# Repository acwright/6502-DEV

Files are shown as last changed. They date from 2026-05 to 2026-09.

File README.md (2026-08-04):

6502-DEV
========

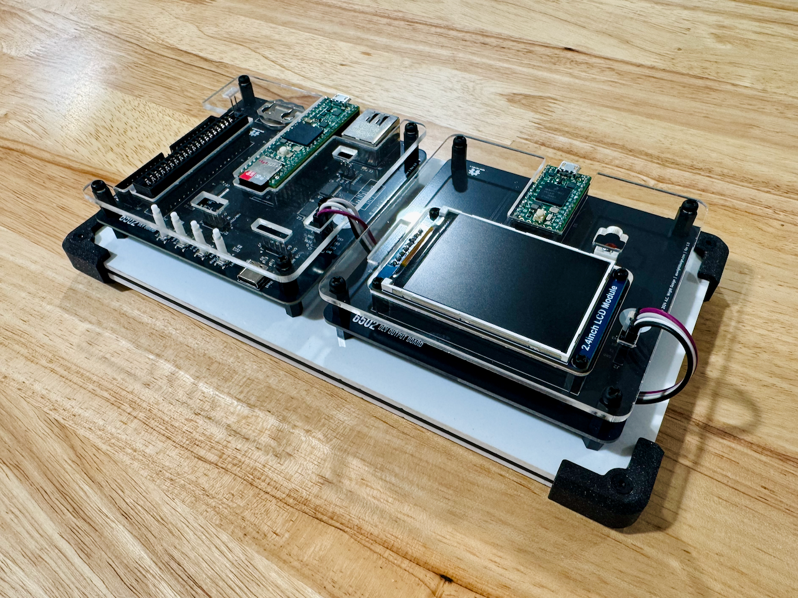
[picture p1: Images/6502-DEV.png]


An **AC6502** retro-style 8-bit computer based on the **65C02** microprocessor.

> 📖 **Guide:** [AC6502 Documentation](https://acwright.github.io/6502-DOCS/) — the user's and programmer's guide for the whole family.
> See [DEV's page in the family appendix](https://acwright.github.io/6502-DOCS/family/dev).

---

## Table of Contents

- [Overview](#overview)
- [Architecture](#architecture)
- [Systems](#systems)
- [Software](#software)
- [Hardware](#hardware)
  - [DEV Board](#dev-board)
  - [DEV Output Board](#dev-output-board)
- [Firmware](#firmware)
  - [DB Emulator](#db-emulator)
  - [DOB Display](#dob-display)
- [CAD](#cad)
- [Production](#production)
- [Schematics](#schematics)
- [Libraries](#libraries)
- [Bill of Materials](#bill-of-materials)
  - [DEV Board](#dev-board-1)
  - [DEV Output Board](#dev-output-board-1)
- [License](#license)

---

## Overview

The AC6502 ecosystem is a family of open-source, 65C02-based computers sharing a common architecture, memory map, and [BIOS](https://github.com/acwright/6502-BIOS). Each computer in the family is purpose-built for a different use case but runs the same software and firmware.

The **DEV** is an emulation-based development system. It replaces the physical 65C02 CPU with a [Teensy 4.1](https://www.pjrc.com/store/teensy41.html) running cycle-accurate 65C02 emulation via [vrEmu6502](https://github.com/visrealm/vrEmu6502).
## Architecture

All AC6502 computers share:

- **CPU**: 65C02 (or accurate emulation)
- **Memory**: 32KB RAM + 32KB ROM, with optional banked RAM expansion
- **Memory Map**: Standardized across the ecosystem — zero page, stack, I/O space ($8000–$9FFF), system ROM, and interrupt vectors at $FFFA–$FFFF
- **Bus**: 16-bit address bus, 8-bit bidirectional data bus, standard 65C02 control signals (RW, PHI2, RESET, IRQ, NMI, RDY, SYNC)
- **BIOS**: A common [BIOS](https://github.com/acwright/6502-BIOS) provides the kernel, monitor, and BASIC interpreter across all systems

## Systems

| Project | Description |
|---|---|
| [6502-ACE](https://github.com/acwright/6502-ACE) | All-in-one Computer Experience — A single board computer |
| [6502-COB](https://github.com/acwright/6502-COB) | Computer On a Backplane — Modular desktop computer with expandable card slots |
| [6502-DEV](https://github.com/acwright/6502-DEV) | Development Environment Vehicle — Emulation-based dev system (YOU ARE HERE) |
| [6502-KIM](https://github.com/acwright/6502-KIM) | Keypad Input Monitor - KIM-1 inspired minimal computer |
| [6502-VCS](https://github.com/acwright/6502-VCS) | Video Computer System — Cartridge-based retro gaming console |

## Software

| Project | Description |
|---|---|
| [6502-BIOS](https://github.com/acwright/6502-BIOS) | The shared BIOS (kernel, monitor, BASIC) for all AC6502 computers |
| [6502-EMULATOR](https://github.com/acwright/6502-EMULATOR) | Emulator for the whole family — desktop app, browser build, and a command line for scripted runs |
| [6502-PRG](https://github.com/acwright/6502-PRG) | Template project for writing assembly language programs |
| [6502-CRT](https://github.com/acwright/6502-CRT) | Template project for writing assembly language cartridges |
| [6502-ASM](https://github.com/acwright/6502-ASM) | Assembly language example programs and demos |
| [6502-BAS](https://github.com/acwright/6502-BAS) | BASIC program listings |
| [6502-WOZMON](https://github.com/acwright/6502-WOZMON) | Wozmon as a standalone ROM |
| [6502-NOP](https://github.com/acwright/6502-NOP) | An all-NOP ROM, for probing a board during bring-up |
| [6502-DOCS](https://github.com/acwright/6502-DOCS) | The documentation site — the guide, the printable reference cards, branding and label artwork |
| [cffs](https://github.com/acwright/cffs) | Builds CompactFlash disk images for the BIOS filesystem |
| [bastok](https://github.com/acwright/bastok) | Tokenizes BASIC listings into `.prg` images, and back |
| [bin2woz](https://github.com/acwright/bin2woz) | Converts a binary into a Wozmon serial upload |

## Hardware

This repository contains KiCad 7.0+ PCB designs for the two boards that make up the DEV system.

### DEV Board
`Hardware/DEV Board/`

The main board hosting the Teensy 4.1. Provides 65C02 bus emulation, SD card storage, Ethernet, USB keyboard/joystick input, and hardware control buttons (Run/Stop, Step, Reset, Frequency). Includes a bus connector and card slot with level shifters for optional real hardware expansion.

### DEV Output Board
`Hardware/DEV Output Board/`

The AV output board hosting a Teensy 4.0 and a 2.4" ILI9341 TFT LCD. Emulates a TMS9918A Video Display Processor and a MOS 6581 SID audio synthesizer, driven in real time via high-speed serial from the DEV Board. The DEV Board sends the same AV packets over USB at the same time, so a browser can render the output in parallel with this board — the two paths are simultaneous, not alternatives.

## Firmware

This repository contains [PlatformIO](https://platformio.org/)-based firmware for both boards.

### DB Emulator
`Firmware/DB Emulator/`

Firmware for the Teensy 4.1 on the DEV Board. Provides:

- Cycle-accurate 65C02 emulation
- SD card ROM/cartridge/program loading and memory snapshots
- Ethernet with mDNS (`6502.local`) and an embedded web control interface
- USB keyboard and joystick support (Xbox 360/One)
- AV packet output to both destinations at once — over USB to the browser (Web Serial API) and over hardware UART at 6 Mbps to the DOB Display
- Serial terminal interface (115200 baud)
- Hardware button control (Run/Stop, Step, Reset, Frequency)
- Variable CPU clock speed

See [Firmware/DB Emulator/README.md](./Firmware/DB%20Emulator/README.md) for setup and usage instructions.

### DOB Display
`Firmware/DOB Display/`

Firmware for the Teensy 4.0 on the DEV Output Board. Provides:

- TMS9918A VDP emulation (all four display modes, 256×192 active area)
- MOS 6581 SID audio emulation (3 voices, ADSR envelopes, PWM audio output)
- AV packet stream input at 6 Mbps over hardware UART from the DB Emulator (which also streams the same packets over USB to the browser)

See [Firmware/DOB Display/README.md](./Firmware/DOB%20Display/README.md) for setup and usage instructions.

## CAD
`CAD/`

3D-printable enclosure parts and laser-cut top panels for the DEV system.

## Production
`Production/`

JLCPCB-ready Gerber files and BOM/CPL for PCB fabrication and assembly.

## Schematics
`Schematics/`

PDF schematics for each board.

## Libraries
`Libraries/`

Shared KiCad symbol and footprint libraries used across all AC6502 hardware projects.

## Bill of Materials

### DEV Board

| Reference | Qty | Value | Description | LCSC | DigiKey | Mouser | Other |
|---|-----|---|---|---|---|---|---|
| BT1 | 1 | CR2032 | Battery Holder | | [BAT-HLD-001-THM-ND](https://www.digikey.com/en/products/filter?keywords=BAT-HLD-001-THM-ND) | [712-BAT-HLD-001-THM](https://www.mouser.com/ProductDetail/712-BAT-HLD-001-THM) | |
| C1–C8 | 8 | 100nF | SMD Capacitor | [C49678](https://www.lcsc.com/search?q=C49678) | | | |
| J1 | 1 | VBAT | Pin Header 1×2 2.54mm | | | | [AMAZON](https://www.amazon.com/Straight-Breakaway-Connector-Breadboard-Electronic/dp/B0FRZW75VS) |
| J2 | 1 | SPI | Pin Header 2×4 2.54mm | | | | [AMAZON](https://www.amazon.com/Uxcell-Double-Straight-Header-Strip/dp/B00X77A472) |
| J3 | 1 | PANEL | Pin Header 2×4 2.54mm | | | | [AMAZON](https://www.amazon.com/Uxcell-Double-Straight-Header-Strip/dp/B00X77A472) |
| J4 | 1 | 6502 Card Connector | Card Edge 2×20 2.54mm | | [A31723-ND](https://www.digikey.com/en/products/filter?keywords=A31723-ND) | [571-5-5530843-4](https://www.mouser.com/ProductDetail/571-5-5530843-4) | |
| J5 | 1 | 6502 Bus | Pin Socket 2×20 2.54mm | | | | [AMAZON](https://www.amazon.com/Female-Headers-Connector-Header-Raspberry/dp/B07DNHS2SJ) |
| J6 | 1 | USB Host | USB Type-C Receptacle | [C2988369](https://www.lcsc.com/search?q=C2988369) | | | |
| J7 | 1 | USB HOST | Pin Header 1×5 2.54mm | | | | [AMAZON](https://www.amazon.com/Straight-Breakaway-Connector-Breadboard-Electronic/dp/B0FRZW75VS) |
| J8 | 1 | RJ45 w/ LEDs | RJ45 8P8C Shielded | | [1278-1052-ND](https://www.digikey.com/en/products/filter?keywords=1278-1052-ND) | | |
| J9 | 1 | ETHERNET | Pin Header 2×3 2.00mm | | | | [AMAZON](https://www.amazon.com/uxcell-2-0mm-Pitch-Double-Headers/dp/B00899WM00) |
| R1–R8 | 8 | 1kΩ | SMD Resistor | [C17513](https://www.lcsc.com/search?q=C17513) | | | |
| R9, R10 | 2 | 56kΩ | SMD Resistor | [C169923](https://www.lcsc.com/search?q=C169923) | | | |
| R11 | 1 | 150Ω | SMD Resistor | [C17471](https://www.lcsc.com/search?q=C17471) | | | |
| SW1 | 1 | Run/Stop | Tact Push Button | [C318884](https://www.lcsc.com/search?q=C318884) | | | |
| SW2 | 1 | Step | Tact Push Button | [C318884](https://www.lcsc.com/search?q=C318884) | | | |
| SW3 | 1 | Clock | Tact Push Button | [C318884](https://www.lcsc.com/search?q=C318884) | | | |
| SW4 | 1 | Reset | Tact Push Button | [C318884](https://www.lcsc.com/search?q=C318884) | | | |
| U1–U3, U5, U6 | 5 | SN74LVC4245APWR | Octal Bus Transceiver | [C7859](https://www.lcsc.com/search?q=C7859) | | | |
| U4 | 1 | Teensy 4.1 | Microcontroller | | | | [PJRC](https://www.pjrc.com/store/teensy41.html) |

### DEV Output Board

| Reference | Qty | Value | Description | DigiKey | Mouser | Other |
|---|-----|---|---|---|---|---|
| C1 | 1 | 3.3nF | Disc Capacitor | | | [AMAZON](https://www.amazon.com/PANMILED-Multilayer-Monolithic-Capacitors-Assortment/dp/B0CYQ1Z4G5) |
| J1 | 1 | AUDIO | JST XH 1×2 2.50mm | [455-2247-ND](https://www.digikey.com/en/products/filter?keywords=455-2247-ND) | | |
| J2 | 1 | SERIAL | Pin Header 1×4 2.54mm | | | [AMAZON](https://www.amazon.com/Straight-Breakaway-Connector-Breadboard-Electronic/dp/B0FRZW75VS) |
| R6 | 1 | 1kΩ | Axial Resistor | [RNF18FTD1K00CT-ND](https://www.digikey.com/en/products/filter?keywords=RNF18FTD1K00CT-ND) | | [AMAZON](https://www.amazon.com/ALLECIN-8W-Metal-Film-Resistor/dp/B0C77TM3NR) |
| U1 | 1 | Waveshare LCD Header | Pin Header 1×8 2.54mm | | | [AMAZON](https://www.amazon.com/Straight-Breakaway-Connector-Breadboard-Electronic/dp/B0FRZW75VS) |
| U2 | 1 | Teensy 4.0 | Microcontroller | | | [PJRC](https://www.pjrc.com/store/teensy40.html) |
| U3 | 1 | Waveshare 2.4in LCD | 2.4" ILI9341 TFT LCD | | | [AMAZON](https://www.amazon.com/dp/B08H24H7KX) |

## License

Hardware designs are released under the [CERN Open Hardware Licence Version 2 – Permissive](https://ohwr.org/cern_ohl_p_v2.txt).  
Firmware is released under the MIT License — [DB Emulator](./Firmware/DB%20Emulator/LICENSE), [DOB Display](./Firmware/DOB%20Display/LICENSE).

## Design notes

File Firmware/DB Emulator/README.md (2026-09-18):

# DB Emulator

A 65C02 CPU emulator firmware for the Teensy 4.1 microcontroller. This project provides a complete hardware-accelerated 65C02 emulation platform with support for RAM, ROM, cartridge loading, I/O devices, and network control.

## Overview

DB Emulator transforms a Teensy 4.1 into a powerful 65C02 computer system emulator. It emulates the complete 65C02 CPU instruction set, memory management, and provides hardware interfaces for keyboards, joysticks, and network connectivity. The emulator can be controlled via serial terminal or through the embedded [web interface](html/README.md). Audio (SID) and video (TMS9918A) register writes are streamed simultaneously to two destinations: over USB (`SerialUSB2`) to the browser, and over the hardware UART (`Serial7` at 6 Mbps) to the DOB Display board for rendering on the ILI9341 TFT and PWM audio output.

### Features

- **Complete 65C02 CPU Emulation**: Accurate cycle-by-cycle emulation using [vrEmu6502](https://github.com/visrealm/vrEmu6502)
- **Memory Management**: 
  - Base RAM: up to 32KB (configurable)
  - Banked RAM: 32KB (default), up to 512KB with PSRAM installed
  - ROM support (full 32KB `BIOS.bin` image; 24KB visible at `$A000-$FFFF` once I/O overlays `$8000-$9FFF`)
  - Cartridge loading (16KB)
- **I/O Support**:
  - USB Keyboard input
  - USB Joystick support (Xbox 360/One controllers)
  - RAM Card (I/O 1 and I/O 2, banked RAM)
  - RTC Card (I/O 3, DS1511Y real-time clock)
  - Storage Card (I/O 4, emulated 256MB CompactFlash backed by `Storage.bin` on SD)
  - Serial Card (I/O 5, Rockwell R6551 ACIA, bound to `SerialUSB1` — the BIOS serial console). It models the standard Serial Card with its `CTS EN` jumper at ground, as every board is built: CTS, DCD and DSR are all tied low, so CTS never stops the transmitter, DCD never stops the receiver, and DSR and DCD both read 0 (active low). There is no card picker and no jumper setting, and none of the Serial Card Pro's lines. Clearing DTR (command bit 0) still turns the receiver, the transmitter and the interrupts off, as it does inside the real chip even though the card leaves the DTR pin unconnected. One thing the real chip does is deliberately left out: a TIC of `00` (command bits 3-2) raises RTS here but does not also stop the transmitter, because this firmware embeds no ROM and cannot check that the image on the SD card is one that survives it — see the comment on `SerialCard::transmitterEnabled`
  - GPIO Card (I/O 6, 65C22 VIA with keyboard/joystick attachments)
  - Sound Card (I/O 7, SID — MOS 6581 emulation, streamed to web interface and DOB Display)
  - Video Card (I/O 8, TMS9918A emulation, streamed to web interface and DOB Display)
- **Storage**:
  - SD card support for loading ROMs, cartridges, and programs
  - Memory snapshot functionality
- **Network Features**:
  - Ethernet connectivity via [QNEthernet](https://github.com/ssilverman/QNEthernet)
  - mDNS discovery (hostname: `6502.local`)
  - Embedded web server with REST API
  - Embedded web control interface (served from SD card)
- **Audio/Video Streaming**: every AV packet is sent to both destinations at once
  - Over USB (`SerialUSB2`) to the browser — SID register writes for Web Audio API synthesis, TMS9918A register writes for canvas rendering, via the Web Serial API (Chrome or Edge required)
  - Over the hardware UART (`Serial7` at 6 Mbps) to the DOB Display board, which renders the same register writes on an ILI9341 TFT with PWM audio output
- **Browser Keyboard Input**: Forwards keyboard events from the web interface to the emulator via REST API
- **Control Options**:
  - Serial terminal interface (115200 baud)
  - Physical buttons (Run/Stop, Step, Reset, Frequency)
  - Web API control
- **Variable Clock Speed**: Adjustable CPU frequency from very slow to maximum speed
- **Real-Time Clock**: TimeLib integration for timestamped operations

## Prerequisites

### Hardware Requirements

- **Teensy 4.1** microcontroller
- **Ethernet module** (built-in on Teensy 4.1)
- **MicroSD card** (optional, for loading ROMs/programs)
- **Development board** compatible with one of the supported configurations
- **USB cable** for programming and serial communication
- **Optional**:
  - USB keyboard
  - USB joystick (Xbox 360/One)
  - PSRAM chip (for extended memory support)

### Software Requirements

- **PlatformIO Core** or **PlatformIO IDE** (VS Code extension)
- **Python 3.x** (usually installed with PlatformIO)
- **Git** (for cloning dependencies)
- **Chromium-based browser** (Chrome or Edge) required for audio/video streaming via Web Serial API
- **Serial terminal software** (optional):
  - CoolTerm (recommended)
  - Arduino Serial Monitor
  - PlatformIO Serial Monitor
  - screen/minicom (Linux/macOS)

### Development Tools (Optional)

- **Visual Studio Code** with PlatformIO extension
- **Teensy Loader Application** (for manual flashing)

## Installation

### 1. Install PlatformIO

#### Option A: PlatformIO IDE (Recommended)

1. **Install Visual Studio Code** from [code.visualstudio.com](https://code.visualstudio.com/)

2. **Install PlatformIO IDE extension**:
   - Open VS Code
   - Go to Extensions (Ctrl+Shift+X / Cmd+Shift+X)
   - Search for "PlatformIO IDE"
   - Click Install

#### Option B: PlatformIO Core (Command Line)

```bash
# macOS/Linux
python3 -c "$(curl -fsSL https://raw.githubusercontent.com/platformio/platformio/master/scripts/get-platformio.py)"

# Or using pip
pip install -U platformio
```

### 2. Clone or Navigate to Project

```bash
cd /path/to/6502/Firmware/DB\ Emulator
```

### 3. Install Dependencies

PlatformIO will automatically install the required libraries on first build:

- **[QNEthernet](https://github.com/ssilverman/QNEthernet)** (v0.27.0+): Ethernet library for Teensy 4.1
- **[ArduinoJson](https://github.com/bblanchon/ArduinoJson)** (v7.0.4+): JSON parsing and generation
- **[AsyncWebServer_Teensy41](https://github.com/khoih-prog/AsyncWebServer_Teensy41)** (v1.7.0+): Asynchronous web server

Additional dependencies included in the project:
- **[vrEmu6502](https://github.com/visrealm/vrEmu6502)**: 6502 CPU emulator core (included in `lib/6502/vrEmu6502/`)
- **TimeLib**: Real-time clock support
- **Bounce2**: Button debouncing library
- **SD**: SD card file system
- **EEPROM**: Non-volatile storage
- **USBHost_t36**: USB host support for Teensy

## Configuration

### Build Flags

You can enable/disable features by uncommenting build flags in `platformio.ini`:

```ini
build_flags = 
    -D USB_TRIPLE_SERIAL    ; Enable triple serial ports (SerialUSB1 + SerialUSB2 for AV streaming)
    ; -D MOUSE_DEBUG        ; Enable mouse debugging output
    ; -D JOYSTICK_DEBUG     ; Enable joystick debugging output
    ; -D KEYBOARD_DEBUG     ; Enable keyboard debugging output
    -D MEM_EXTMEM           ; Use external PSRAM
```

### SD Card Setup (Optional)

1. **Format SD card** as FAT32
2. **Create directories** on the SD card:
   ```
   /ROMs/       - BIOS and operating system ROMs
   /Carts/      - Cartridge images
   /Programs/   - User programs
   /Snapshots/  - Memory snapshots
   /WWW/        - Embedded web application (See README in /html folder)
   ```
3. **Place ROM or PRG files** (.bin or .prg format) in appropriate directories

**Auto-boot Configuration**:
- Place `BIOS.bin` in the `ROMs` directory for automatic loading

## Building and Uploading

### Using PlatformIO IDE (VS Code)

1. **Open the project** in VS Code (File → Open Folder)

2. **Build the project**:
   - Click the ✓ (Build) button in the status bar
   - Or: Terminal → Run Build Task
   - Or: Press `Ctrl+Alt+B` / `Cmd+Alt+B`

3. **Upload to Teensy**:
   - Connect Teensy 4.1 via USB
   - Click the → (Upload) button in the status bar
   - Or: Use the upload task from the command palette
   - The Teensy will automatically enter bootloader mode

### Using PlatformIO Core (Command Line)

```bash
# Build for DevBoard 1 (Rev 1.0 and newer)
platformio run -e devboard_1

# Build for DevBoard 0 (Rev 0.0 legacy board)
platformio run -e devboard_0

# Upload to Teensy
platformio run -e devboard_1 --target upload

# Build and upload
platformio run -e devboard_1 -t upload

# Open serial monitor
platformio device monitor -b 115200

# Build, upload, and monitor
platformio run -e devboard_1 -t upload && platformio device monitor -b 115200
```

### Manual Upload with Teensy Loader

1. Build the firmware using PlatformIO
2. Locate the compiled `.hex` file in `.pio/build/devboard_X/firmware.hex`
3. Open Teensy Loader application
4. Load the `.hex` file
5. Press the button on the Teensy to enter bootloader mode
6. Click "Program" in Teensy Loader

## Usage

### Serial Terminal Control

Connect to the Teensy via serial terminal at **115200 baud**:

```bash
# Using PlatformIO
platformio device monitor -b 115200

# Using screen (macOS/Linux)
screen /dev/ttyACM0 115200

# Using CoolTerm
# Set port to Teensy, baud rate to 115200
```

### Serial Commands

Once connected, you'll see the emulator banner and status. Available commands:

#### Execution Control
- **`R`** - Run/Stop: Toggle emulator execution
- **`S`** - Step: Execute one CPU instruction (when stopped)
- **`K`** - Tick: Execute one clock cycle (when stopped)
- **`T`** - Reset: Hardware reset of the emulator

#### Memory Management
- **`A`** - Toggle RAM: Enable/disable RAM
- **`O`** - Toggle ROM: Enable/disable ROM
- **`L`** - Toggle Cart: Enable/disable cartridge

#### File Management
- **`M`** - List ROMs: Show available ROM files from SD card
- **`C`** - List Carts: Show available cartridge files
- **`U`** - List Programs: Show available user programs
- **`0-7`** - Load File: Load the selected file (after listing)
- **`[`** - Previous Page: Navigate file lists
- **`]`** - Next Page: Navigate file lists

#### Configuration
- **`+`** - Increase Frequency: Speed up CPU clock
- **`-`** - Decrease Frequency: Slow down CPU clock

#### Information & Debugging
- **`F`** - Info: Display system information and status
- **`G`** - Log: Show current CPU state
- **`P`** - Snapshot: Save current RAM state to SD card

### Web Control Interface

1. **Ensure Teensy is connected** to your network via Ethernet

2. **Note the IP address** from the serial output on boot

3. **Access via mDNS** (if supported):
   ```
   http://6502.local/
   ```

4. **Or access via direct IP**:
   ```
   http://192.168.1.XXX/
   ```

5. **Use the web interface** to control the emulator (see [Web Interface documentation](html/README.md))

#### Audio/Video Streaming

Every SID and TMS9918A register write is emitted as a 4-byte AV packet, and `avSend()` in `lib/6502/IO/AVStream.h` writes each packet to **both** outputs on every call. The two paths are simultaneous, not alternatives — neither has to be connected for the other to work.

**Browser rendering (USB, `SerialUSB2`)**

- The Teensy must be USB-connected to the same machine running the browser
- Click **Connect AV** in the VIDEO panel to open the USB serial link
- Requires **Chrome or Edge** (Web Serial API); requires HTTPS or localhost
- Audio and video are rendered entirely in the browser; the Teensy streams register writes only
- Click **Mute** to toggle audio output

**Hardware rendering (`HWSERIAL` / `Serial7` at 6 Mbps)**

The same packets go out the hardware UART to the DEV Output Board, whose [DOB Display](../DOB%20Display/README.md) firmware opens `Serial1` at the same 6000000 baud and parses the identical 4-byte format. It renders the TMS9918A output on the 2.4" ILI9341 TFT and the SID output as PWM audio. Any other device speaking the same protocol can be attached instead.

### Physical Controls

If your development board has physical buttons:

- **INT/CLK Button**: Change clock frequency
- **STEP Button**: Execute one instruction
- **RUN/STOP Button**: Toggle execution
- **RESET Button**: Hardware reset (DevBoard 1 only)

## API Endpoints

The embedded web server provides RESTful API endpoints:

### GET /info
Returns system information and CPU state in JSON format:
```json
{
  "address": 65535,
  "cartEnabled": true,
  "cartFile": "game.bin",
  "cpuAccumulator": 0,
  "cpuOpcodeCycle": 0,
  "cpuPC": 65520,
  "cpuStackPointer": 255,
  "cpuStatus": 32,
  "cpuX": 0,
  "cpuY": 0,
  "data": 234,
  "freqLabel": "1 MHz",
  "freqPeriod": 1,
  "ipAddress": "192.168.1.100",
  "isRunning": false,
  "lastSnapshot": 1234567890,
  "programFile": "",
  "romFile": "BIOS.bin",
  "rtc": 1737590400,
  "rw": 1,
  "soundEnabled": true,
  "version": "1.0",
  "videoEnabled": true,
  "avStreamConnected": false
}
```

### GET /memory?target={ram|rom}&page={n}
Returns a memory dump, one 256-byte page per request:
- `target`: `ram` or `rom` (required; returns 400 if missing or any other value)
- `page`: Page number, `0`-`127` for both targets (required; returns 400 if missing or out of range)
  - RAM page `n` covers `$0000 + (n * $100)`, so page 0 is `$0000` and page 127 is `$7F00`
  - ROM page `n` is an offset from `ROM_START`, covering `$8000 + (n * $100)` — the visible ROM window at `$A000` begins at page 32
- Optional: `formatted=true` returns `text/plain` as space-separated hex bytes; omitted, the response is raw `application/octet-stream`

### GET /storage?target={rom|cart|program}&page={n}
Lists files in storage:
- `target`: `rom`, `cart`, or `program`
- `page`: Page number for pagination
- Returns JSON array of filenames

### GET /load?target={rom|cart|program}&filename={name}
Loads a file from SD card:
- `target`: Memory region to load into
- `filename`: Name of file to load

### GET /control?command={cmd}
Executes control command:
- `command`: Single letter command (same as serial commands)
- Examples: `r` (run/stop), `s` (step), `t` (reset), `+` (inc freq)

### GET /keyboard?action={down|up}&keycode={XX}
Forwards browser keyboard events to the emulator:
- `action`: `down` or `up` (required; returns 400 if missing or invalid)
- `keycode`: 1–2 character hex string representing a USB HID keycode (e.g. `04` for 'a') (required; returns 400 if missing)
- Returns 200 on success

**Note:** Audio/video data does not flow over REST. It streams over USB (`SerialUSB2`, Web Serial API) and over the hardware UART (`Serial7`) to the DOB Display, simultaneously. See the Audio/Video Streaming section above.

## Troubleshooting

### Build Errors

**Problem**: Library dependencies not found

**Solutions**:
- Run `platformio lib install` to fetch dependencies
- Delete `.pio` folder and rebuild
- Check internet connection for library downloads

**Problem**: Compilation errors with PSRAM

**Solutions**:
- Ensure `MEM_EXTMEM` flag matches your hardware configuration
- Check PSRAM wiring and connections

### Upload Issues

**Problem**: Teensy not detected

**Solutions**:
- Install Teensy Udev rules (Linux) or drivers (Windows)
- Press the physical button on Teensy to enter bootloader mode
- Try a different USB cable or port
- Check `platformio device list` to see connected devices

**Problem**: Upload fails or times out

**Solutions**:
- Manually press Teensy button during upload
- Use Teensy Loader application instead
- Update Teensy udev rules/drivers

### Runtime Issues

**Problem**: Emulator doesn't start or crashes

**Solutions**:
- Check serial output for error messages
- Verify SD card is properly formatted (FAT32)
- Ensure ROM files are valid 65C02 binaries
- Reset via serial command `T` or power cycle

**Problem**: Network features not working

**Solutions**:
- Verify Ethernet cable is connected
- Check DHCP is available on your network
- Look for IP address in serial output
- Try accessing via direct IP instead of mDNS
- Ensure firewall allows port 80

**Problem**: USB devices not recognized

**Solutions**:
- Check device compatibility (Xbox controllers work best)
- Try different USB ports on the hub
- Verify USB host power supply is adequate
- Enable debug flags to see USB enumeration

**Problem**: SD card files not loading

**Solutions**:
- Verify SD card is formatted as FAT32
- Check file permissions and naming
- Ensure directories exist: `/ROMs/`, `/Carts/`, `/Programs/`
- Files should have `.bin` extension
- Try reinserting SD card

### AV Streaming Issues

**Problem**: Connect AV button not visible

**Solutions**:
- Must use Chrome or Edge (Web Serial API is not supported in Firefox or Safari)
- The Web Serial API requires a **secure context**. When accessing via `http://6502.local` (plain HTTP), Chrome hides the API even though your browser supports it. Choose one of the following workarounds:

  **Option 1 — Chrome flag (easiest, for local development)**
  1. In Chrome, navigate to `chrome://flags/#unsafely-treat-insecure-origin-as-secure`
  2. Add `http://6602.local` to the list and set it to **Enabled**
  3. Relaunch Chrome

  **Option 2 — Serve over HTTPS**
  Configure the Teensy's web server with a self-signed TLS certificate. The browser will show a certificate warning; accept it once and the API will become available.

  **Option 3 — Local proxy via localhost**
  Run a local reverse proxy (e.g. `nginx` or `caddy`) that forwards `http://localhost` to `http://6602.local`. Because `localhost` is always treated as a secure context, the Web Serial API will be available.

**Problem**: No video or audio after connecting

**Solutions**:
- Verify USB cable supports data (not charge-only)
- Check `SerialUSB2` is initialized (`USB_TRIPLE_SERIAL` build flag must be set)
- Try disconnecting and reconnecting

**Problem**: Audio glitches or dropouts

**Solutions**:
- Lower the CPU frequency
- Ensure the browser tab is not throttled or backgrounded
- Close other audio-intensive applications

## Development

### Project Structure

```
DB Emulator/
├── lib/
│   └── 6502/                 # Custom 6502 emulation library
│       ├── 6502.h            # Main library header
│       ├── constants.h       # System constants
│       ├── macros.h          # Utility macros
│       ├── pins.h            # Pin definitions
│       ├── CPU/              # CPU emulator wrapper
│       │   └── [vrEmu6502](https://github.com/visrealm/vrEmu6502)/        # Core 6502 emulator
│       ├── RAM/              # RAM emulation
│       ├── ROM/              # ROM emulation
│       ├── Cart/             # Cartridge support
│       └── IO/               # I/O device emulation
│           ├── AVStream.h    # AV streaming protocol (SerialUSB2 + HWSERIAL)
│           ├── SoundCard.*   # SID (MOS 6581) emulation
│           └── VideoCard.*   # TMS9918A emulation
├── src/
│   └── main.cpp              # Main firmware code
├── include/                  # Additional headers
├── test/                     # Unit tests
├── html/                     # Web interface source
└── platformio.ini            # PlatformIO configuration
```

### Adding Features

1. **New I/O Device**: Extend the `IO` class in `lib/6502/IO/`
2. **Memory Extensions**: Modify memory maps in `constants.h`
3. **New Commands**: Add cases to `onCommand()` in `main.cpp`
4. **Web API**: Add routes in `initServer()` function

### Memory Map

```
$0000 - $00FF : Zero Page
$0100 - $01FF : Stack
$0200 - $02FF : Input Buffer
$0300 - $03FF : Kernal Variables
$0400 - $07FF : User Variables
$0800 - $7FFF : Program RAM (30KB)
$8000 - $83FF : I/O Slot 1 (1KB) - RAM Card
$8400 - $87FF : I/O Slot 2 (1KB) - RAM Card
$8800 - $8BFF : I/O Slot 3 (1KB) - RTC Card
$8C00 - $8FFF : I/O Slot 4 (1KB) - Storage Card
$9000 - $93FF : I/O Slot 5 (1KB) - Serial Card
$9400 - $97FF : I/O Slot 6 (1KB) - GPIO Card
$9800 - $9BFF : I/O Slot 7 (1KB) - Sound Card (SID)
$9C00 - $9FFF : I/O Slot 8 (1KB) - Video Card (TMS9918A)
$A000 - $BFFF : ROM (8KB)
$C000 - $FFFF : ROM/Cartridge (16KB)
```

**Note**: The cartridge space ($C000-$FFFF) can be used for either ROM or cartridge data depending on configuration.

### Debug Output

Enable debug flags in `platformio.ini` for verbose logging:

```ini
-D KEYBOARD_DEBUG    ; Log all keyboard events
-D JOYSTICK_DEBUG    ; Log joystick button presses
```

## Performance

- **Maximum Emulation Speed**: 1 MHz (Teensy 4.1 @ 600 MHz)
- **Accurate Timing**: Down to microsecond precision
- **Memory**: 32KB base RAM + 32KB banked RAM (default), up to 544KB total with PSRAM (32KB base + 512KB banked)
- **Storage**: Limited only by SD card size

## Related Documentation

- [Web Interface (html/)](html/README.md)
- [PlatformIO Documentation](https://docs.platformio.org/)
- [Teensy 4.1 Documentation](https://www.pjrc.com/store/teensy41.html)
- [6502 CPU Reference](http://www.6502.org/)

## License

See LICENSE file in project root.

## Credits

- © 2024 A.C. Wright Design
- Based on [vrEmu6502](https://github.com/visrealm/vrEmu6502) by Troy Schrapel
- Uses [QNEthernet](https://github.com/ssilverman/QNEthernet) library by Shawn Silverman
- Uses [AsyncWebServer_Teensy41](https://github.com/khoih-prog/AsyncWebServer_Teensy41) library by Khoi Hoang
- Uses [ArduinoJson](https://github.com/bblanchon/ArduinoJson) library by Benoit Blanchon

## Version History

- **v1.0.0**: Initial release with full 65C02 emulation, network support, and web API

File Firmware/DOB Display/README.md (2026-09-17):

# DOB Display

DOB Display is the AV output firmware for the DOB (DEV Output Board). It emulates a TMS9918A Video Display Processor and a MOS 6581 SID audio synthesizer, driven in real time by AV packets from the DB Emulator over high-speed hardware serial.

## Features

- **TMS9918A VDP Emulator** - Full software emulation of all four TMS9918A display modes
- **320x240 Display with Borders** - 256×192 active area centered in a 320×240 canvas with TMS9918-style color borders
- **8-bit Indexed Framebuffer** - 76,800-byte indexed framebuffer with 16-entry RGB565 TMS9918A palette; half the RAM of a 16-bit framebuffer
- **SID Audio Emulator** - 3-voice MOS 6581 software synthesizer with triangle, sawtooth, pulse, and noise waveforms and full ADSR envelopes, output via 8-bit PWM at 44.1 kHz
- **AV Packet Protocol** - 4-byte AV packet stream received at 6 Mbps over hardware UART (Serial1) from the DB Emulator
- **Dual Serial Input** - USB Serial accepted as a fallback for testing without hardware
- **~60 FPS Rendering** - Full-frame re-render from VRAM state every ~17 ms

## Hardware

- **MCU**: Teensy 4.0 (600 MHz ARM Cortex-M7)
- **Display**: ILI9341 320×240 TFT LCD
- **Audio**: 8-bit PWM output (pin 14) into passive speaker via RC low-pass filter
- **Communication**: USB Serial + hardware UART Serial1 at 6 Mbps

### Audio Hardware Notes

The audio output on pin 14 is a PWM signal with a ~2.34 MHz carrier. To drive a small 8Ω speaker you need an RC low-pass filter between pin 14 and the speaker:

- **R**: 1 kΩ
- **C**: 3.3 nF to ground (f_c ≈ 48 kHz)

This removes the PWM carrier while passing the full audio band.

## AV Packet Format

All communication uses 4-byte packets: `{ 0xAA, type, a, b }`

| Type | Value | Description |
|---|---|---|
| `AV_TYPE_SOUND` | `0x01` | SID register write: `a` = register (0x00–0x1F), `b` = value |
| `AV_TYPE_VIDEO_DATA`  | `0x02` | VRAM data write at current address pointer (auto-increments) |
| `AV_TYPE_VIDEO_REG` | `0x03` | TMS9918A register write: `a` = register (0–7), `b` = value |
| `AV_TYPE_VIDEO_ADDR`  | `0x04` | Set VRAM address: `a` = high 6 bits, `b` = low 8 bits |
| `AV_TYPE_RESET` | `0xFE` | Reset all VRAM, TMS9918A registers, SID state, and address pointer |

## Display Modes

| M1 | M2 | M3 | Mode |
|----|----|----|---|
| 0  | 0  | 0  | Graphics I — 32×24 tiles, per-8-char color |
| 0  | 0  | 1  | Graphics II — 32×24 tiles, per-pixel color |
| 1  | 0  | 0  | Text — 40×24 tiles, 6px wide, R7 fg/bg |
| 0  | 1  | 0  | Multicolor — 64×48 fat pixels (4×4 each) |

Sprites are rendered in all modes except Text (up to 32 sprites, max 4 visible per scanline, 8×8 or 16×16, with optional magnification).

## Installation

### Prerequisites

- [PlatformIO](https://platformio.org/) - Cross-platform build system
- [Visual Studio Code](https://code.visualstudio.com/) (recommended) with PlatformIO extension
- Teensy 4.0 board
- ILI9341 compatible TFT display

### Hardware Setup

Connect the display and speaker to your Teensy 4.0 according to the pin definitions in `lib/DOBDisplay/pins.h`.

## Building and Uploading

### Using PlatformIO CLI

1. Clone the repository:
   ```bash
   git clone <repository-url>
   cd "DOB Display"
   ```

2. Build the project:
   ```bash
   pio run
   ```

3. Upload to Teensy 4.0:
   ```bash
   pio run --target upload
   ```

### Using VS Code

1. Open the project folder in VS Code
2. Click the PlatformIO icon in the sidebar
3. Under "Project Tasks" → "teensy" → "General":
   - Click "Build" to compile
   - Click "Upload" to flash the firmware

## Project Structure

```
DOB Display/
├── src/
│   └── main.cpp              # Main firmware — VDP emulator, SID engine, AV packet processing
├── lib/
│   └── DOBDisplay/
│       ├── constants.h       # AV protocol constants, display geometry, TMS9918A RGB565 palette
│       ├── pins.h            # Hardware pin assignments
│       └── DOBDisplay.h # Main library header
├── platformio.ini            # Build configuration
└── README.md
```

## License

See [LICENSE](LICENSE) for details.

## Author

© 2026 A.C. Wright Design

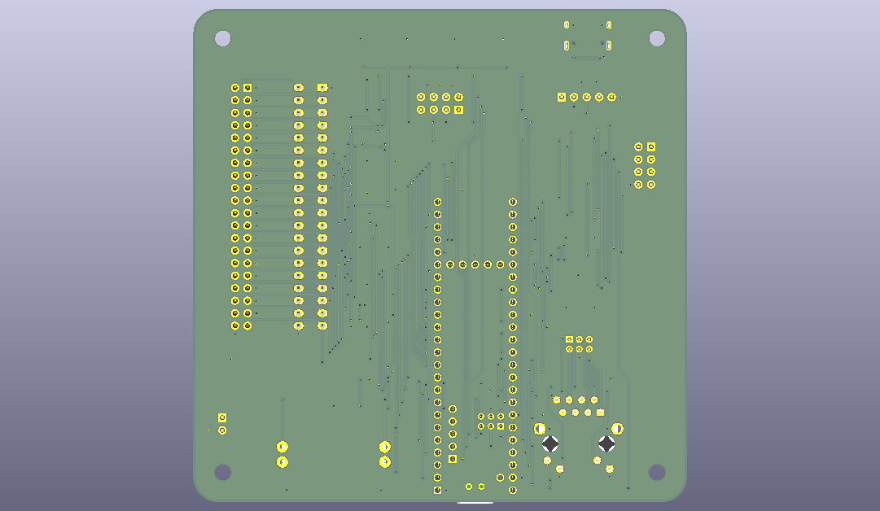
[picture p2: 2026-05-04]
CAD/Images/DEV Board/Rev 1.0/Back.png

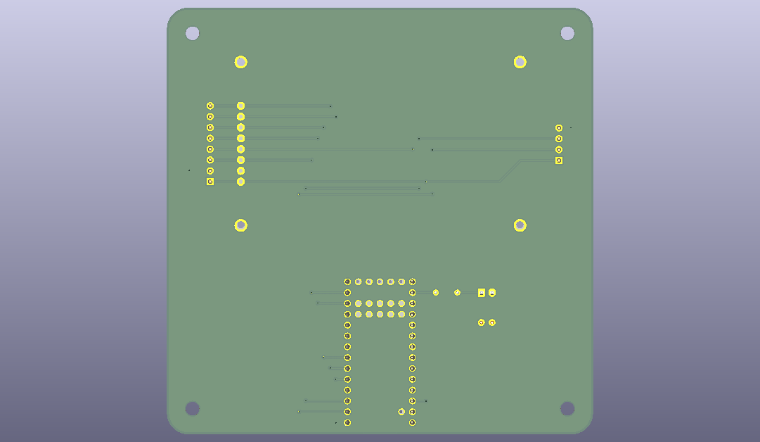
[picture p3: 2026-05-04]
CAD/Images/DEV Output Board/Rev 1.0/Back.png

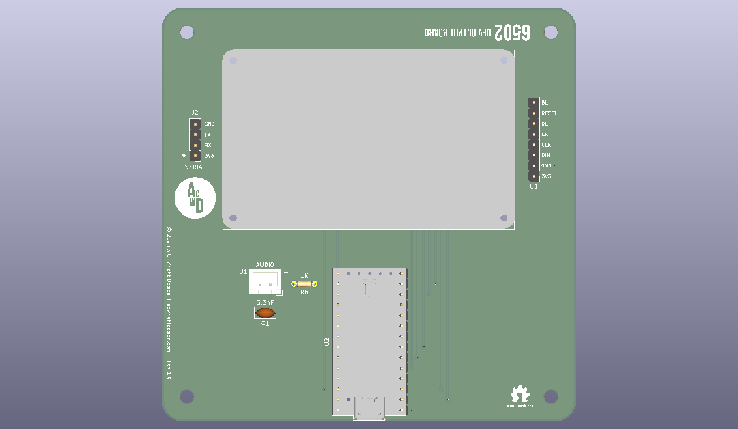
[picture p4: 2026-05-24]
CAD/Images/DEV Output Board/Rev 1.0/Front.png

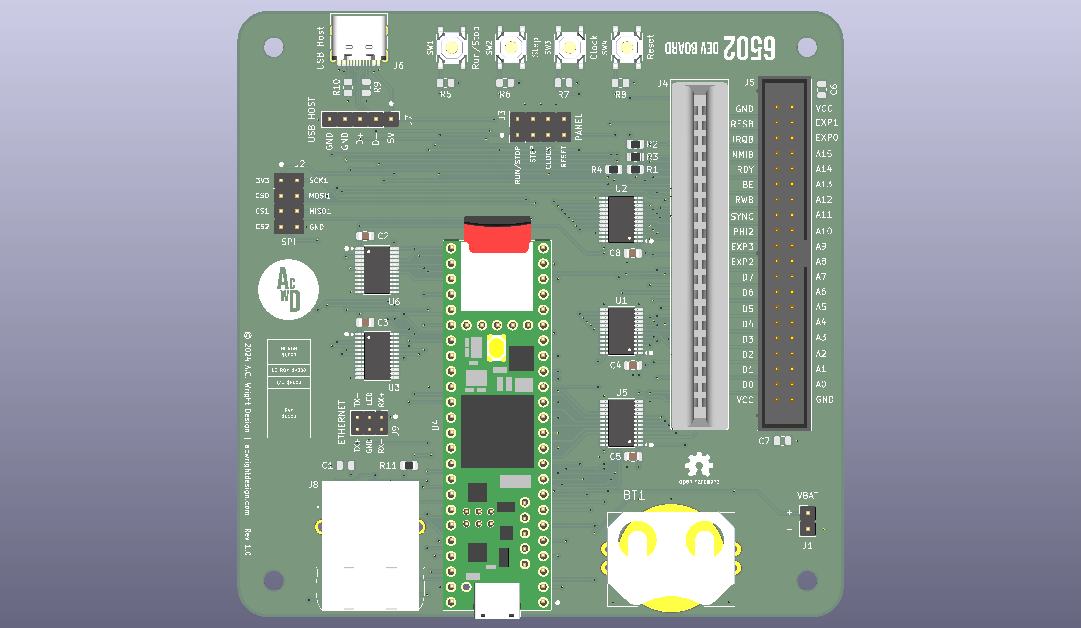
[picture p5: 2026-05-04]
CAD/Images/DEV Board/Rev 1.0/Front.png

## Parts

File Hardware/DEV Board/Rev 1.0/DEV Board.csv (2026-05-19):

Reference | Value | Qty | Description | Footprint | LCSC | Digikey | Mouser | Other
BT1 | CR2032 | 1 | CR2032 | 6502 Parts:BAT_BAT-HLD-001-THM |  | BAT-HLD-001-THM-ND | 712-BAT-HLD-001-THM
C1,C2,C3,C4,C5,C6,C7,C8 | 100nF | 8 | Unpolarized Capacitor | Capacitor_SMD:C_0805_2012Metric | C49678
J1 | VBAT | 1 | Generic connector, single row, 01x02, script generated (kicad-library-utils/schlib/autogen/connector/) | Connector_PinHeader_2.54mm:PinHeader_1x02_P2.54mm_Vertical |  |  |  | https://www.amazon.com/Straight-Breakaway-Connector-Breadboard-Electronic/dp/B0FRZW75VS
J2 | SPI | 1 | Generic connector, double row, 02x04, odd/even pin numbering scheme (row 1 odd numbers, row 2 even numbers), script generated (kicad-library-utils/schlib/autogen/connector/) | Connector_PinHeader_2.54mm:PinHeader_2x04_P2.54mm_Vertical |  |  |  | https://www.amazon.com/Uxcell-Double-Straight-Header-Strip/dp/B00X77A472
J3 | PANEL | 1 | Generic connector, double row, 02x04, odd/even pin numbering scheme (row 1 odd numbers, row 2 even numbers), script generated (kicad-library-utils/schlib/autogen/connector/) | Connector_PinHeader_2.54mm:PinHeader_2x04_P2.54mm_Vertical |  |  |  | https://www.amazon.com/Uxcell-Double-Straight-Header-Strip/dp/B00X77A472
J4 | 6502 Card Connector | 1 | Generic connector, double row, 02x20, odd/even pin numbering scheme (row 1 odd numbers, row 2 even numbers), script generated (kicad-library-utils/schlib/autogen/connector/) | 6502 Parts:RHDR40W82P485X254_2X20_5740X93 |  | A31723-ND | 571-5-5530843-4
J5 | 6502 Bus | 1 | Generic connector, double row, 02x20, odd/even pin numbering scheme (row 1 odd numbers, row 2 even numbers), script generated (kicad-library-utils/schlib/autogen/connector/) | 6502 Parts:6502 Bus Connector |  |  |  | https://www.amazon.com/Female-Headers-Connector-Header-Raspberry/dp/B07DNHS2SJ
J6 | USB Host | 1 | USB 2.0-only 16P Type-C Receptacle connector | Connector_USB:USB_C_Receptacle_HRO_TYPE-C-31-M-12 | C2988369
J7 | USB HOST | 1 | Generic connector, single row, 01x05, script generated (kicad-library-utils/schlib/autogen/connector/) | Connector_PinHeader_2.54mm:PinHeader_1x05_P2.54mm_Vertical |  |  |  | https://www.amazon.com/Straight-Breakaway-Connector-Breadboard-Electronic/dp/B0FRZW75VS
J8 | RJ45_LED | 1 | RJ connector, 8P8C (8 positions 8 connected), two LEDs, Shielded | 6502 Parts:J1B1211CCD |  | 1278-1052-ND
J9 | ETHERNET | 1 | Generic connector, double row, 02x03, odd/even pin numbering scheme (row 1 odd numbers, row 2 even numbers), script generated (kicad-library-utils/schlib/autogen/connector/) | Connector_PinHeader_2.00mm:PinHeader_2x03_P2.00mm_Vertical |  |  |  | https://www.amazon.com/uxcell-2-0mm-Pitch-Double-Headers/dp/B00899WM00
R1,R2,R3,R4,R5,R6,R7,R8 | 1k | 8 | Resistor | Resistor_SMD:R_0805_2012Metric | C17513
R9,R10 | 56k | 2 | Resistor | Resistor_SMD:R_0805_2012Metric | C169923
R11 | 150 | 1 | Resistor | Resistor_SMD:R_0805_2012Metric | C17471
SW1 | Run/Stop | 1 | Push button switch, generic, two pins | 6502 Parts:SW_TS-1187A-B-A-B | C318884
SW2 | Step | 1 | Push button switch, generic, two pins | 6502 Parts:SW_TS-1187A-B-A-B | C318884
SW3 | Clock | 1 | Push button switch, generic, two pins | 6502 Parts:SW_TS-1187A-B-A-B | C318884
SW4 | Reset | 1 | Push button switch, generic, two pins | 6502 Parts:SW_TS-1187A-B-A-B | C318884
U1,U2,U3,U5,U6 | SN74LVC4245APWR | 5 | Octal Bus Transceiver And 3.3-V To 5-V Shifter With 3-State Outputs | Package_SO:TSSOP-24_4.4x7.8mm_P0.65mm | C7859
U4 | Teensy4.1 | 1 |  | 6502 Parts:Teensy41 |  |  |  | https://www.pjrc.com/store/teensy41.html

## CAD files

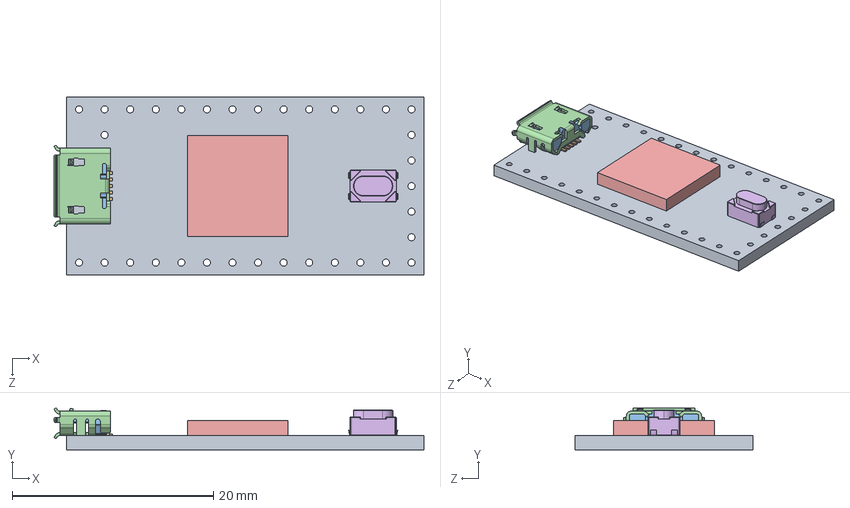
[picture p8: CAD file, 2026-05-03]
Models/Teensy_4.0_Assembly.step
36.8 x 4.12 x 17.7 mm
Teensy_4.0_PCB
Micro USB-B Female 5Pin SMD
NXP iMXRT1062
SKRPACE010 v4

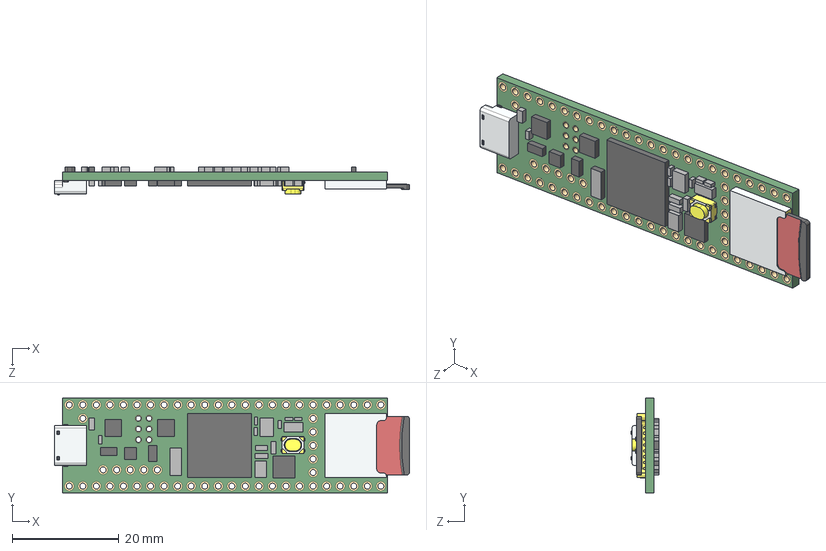
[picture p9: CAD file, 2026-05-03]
Models/Teensy_4.1_Assembly.step
66.6 x 17.8 x 5.27 mm

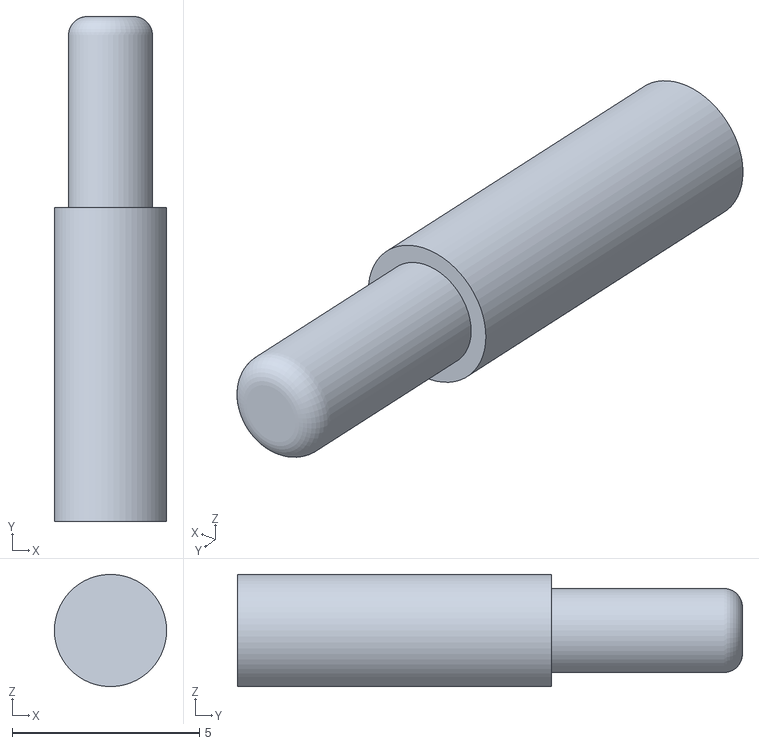
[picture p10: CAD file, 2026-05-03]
CAD/Bases/Button.stl
3.00 x 13.5 x 3.00

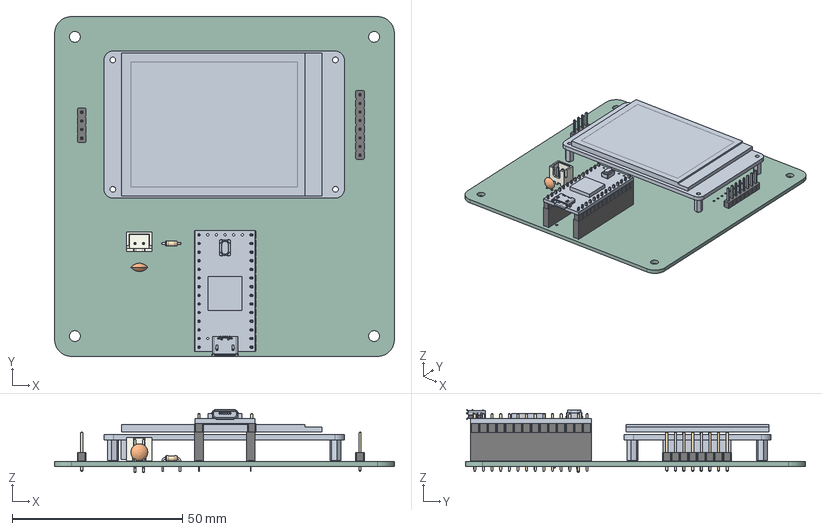
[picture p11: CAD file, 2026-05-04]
CAD/Models/DEV Output Board/Rev 1.0/DEV Output Board.step
100.0 x 100.0 x 18.6 mm
C_Disc_D5.0mm_W2.5mm_P2.50mm
Waveshare 2.4in LCD
R_Axial_DIN0204_L3.6mm_D1.6mm_P5.08mm_Horizontal
PinHeader_1x08_P2.54mm_Vertical
Teensy_4.0_PCB
Micro USB-B Female 5Pin SMD
NXP iMXRT1062
SKRPACE010 v4
PinSocket_1x14_P2.54mm_Vertical x 2
PinHeader_1x14_P2.54mm_Vertical x 2
PinHeader_1x04_P2.54mm_Vertical
JST_XH_B2B-XH-A_1x02_P2.50mm_Vertical
DEV Output Board_PCB

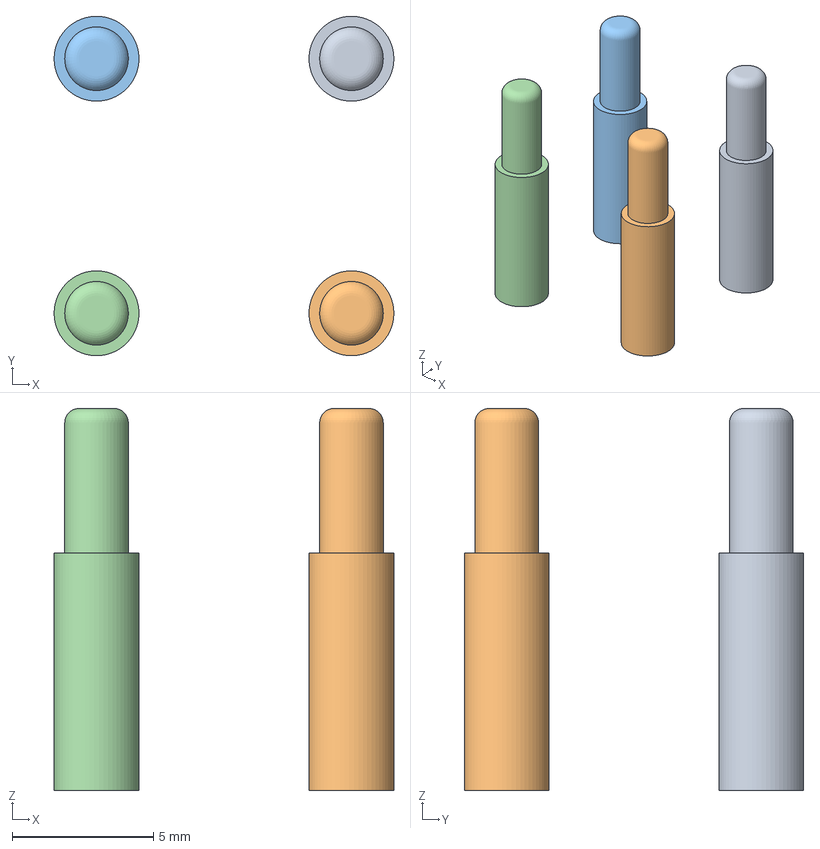
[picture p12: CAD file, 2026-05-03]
CAD/Bases/Buttons.3mf
12.0 x 12.0 x 13.5 mm

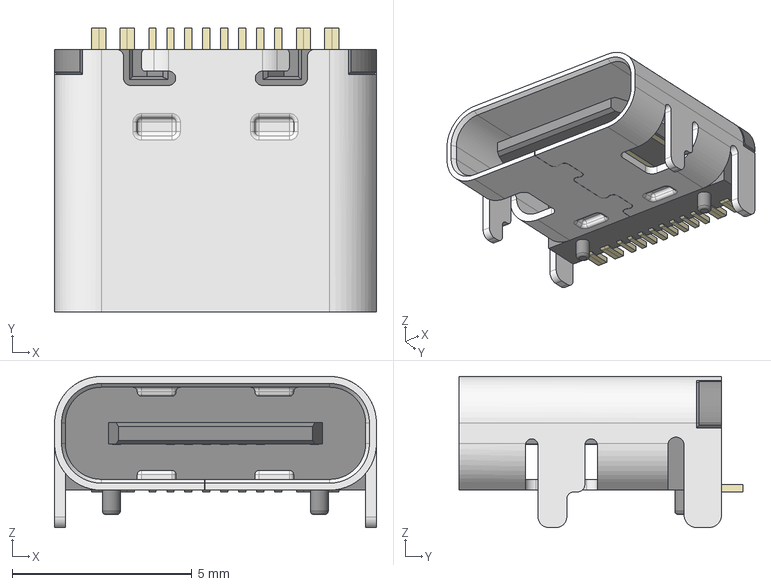
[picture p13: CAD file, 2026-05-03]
Models/HRO_TYPE-C-31-M-12.step
8.95 x 7.90 x 4.20 mm

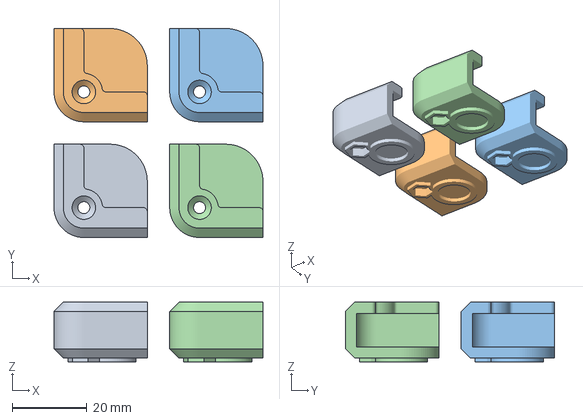
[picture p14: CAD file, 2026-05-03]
CAD/Bases/Corner.3mf
56.0 x 56.0 x 16.0 mm

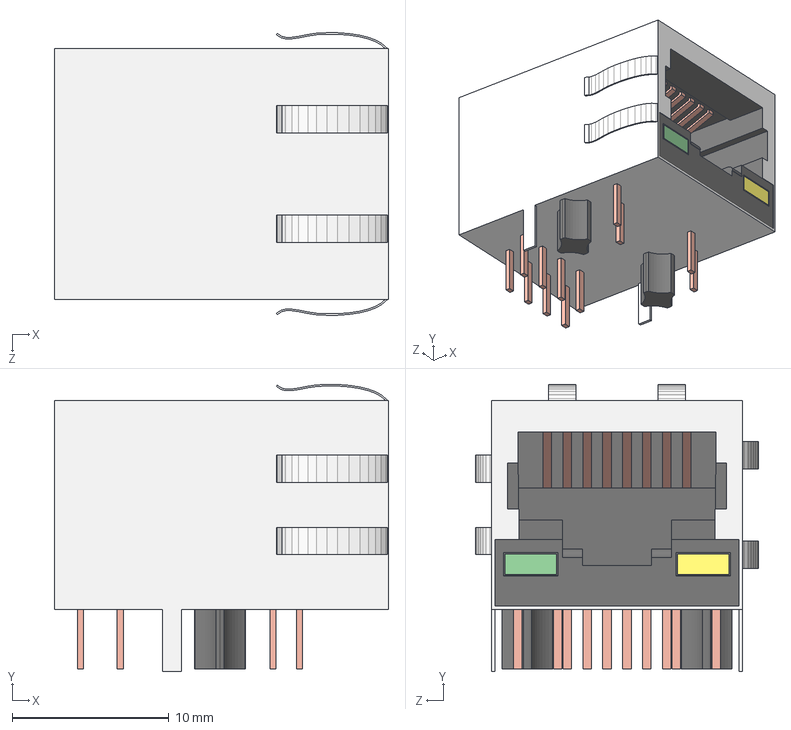
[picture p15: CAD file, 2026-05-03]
Models/J1B1211CCD.STEP
21.3 x 18.3 x 18.0 mm

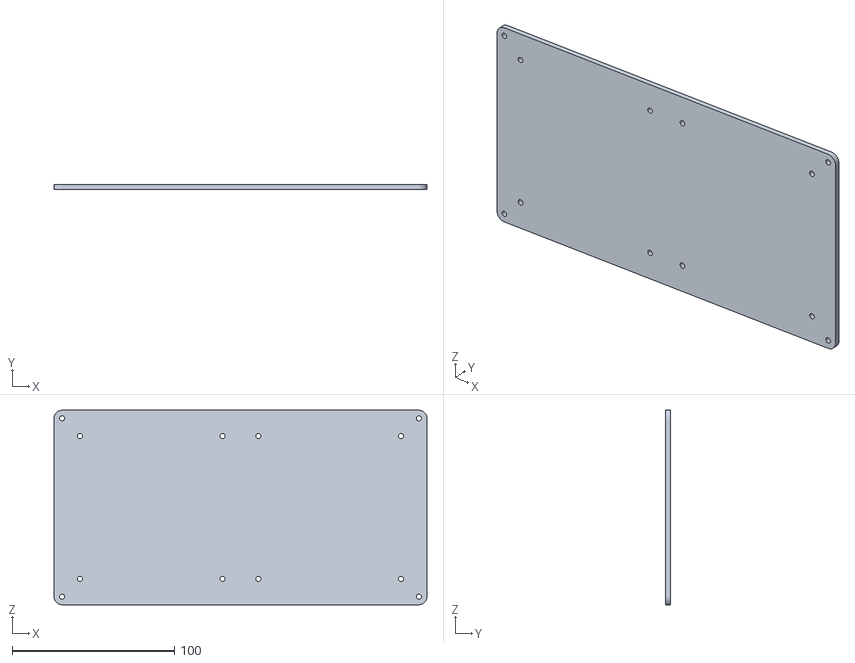
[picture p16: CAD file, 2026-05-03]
CAD/Bases/Plate.stl
230.0 x 3.00 x 120.0

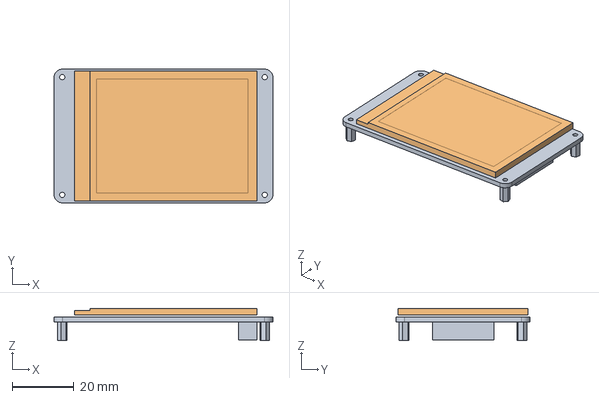
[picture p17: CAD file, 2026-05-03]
Models/Waveshare 2.4in LCD.step
70.8 x 43.3 x 10.5 mm

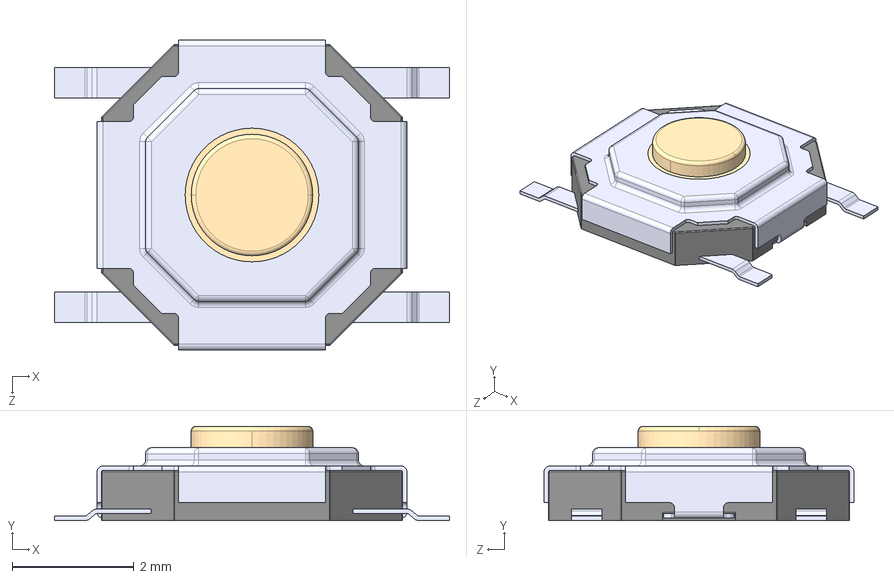
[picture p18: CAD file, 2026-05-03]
Models/TS-1187A-B-A-B.step
6.50 x 1.55 x 5.10 mm

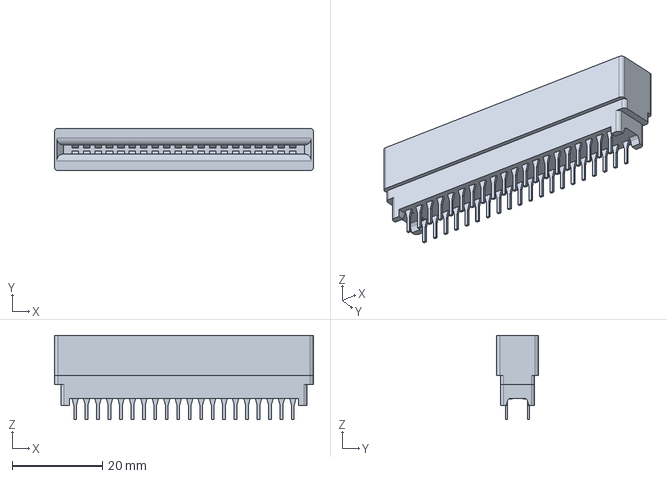
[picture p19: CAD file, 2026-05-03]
Models/5-5530843-4.step
57.4 x 9.35 x 18.7 mm

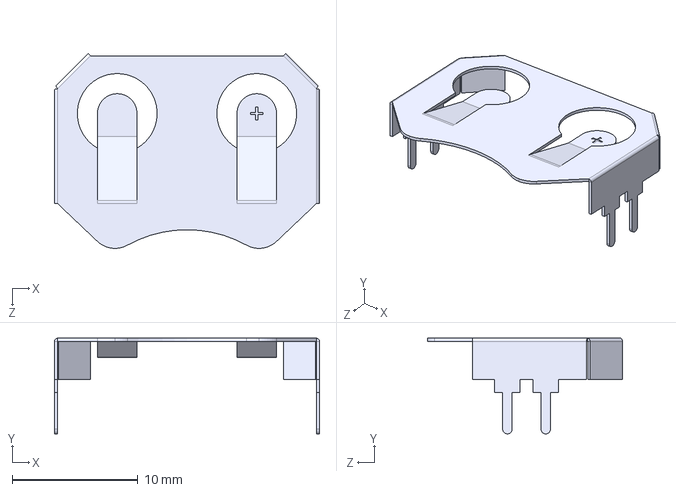
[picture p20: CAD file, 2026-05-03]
Models/BAT-HLD-001-THM.step
21.1 x 7.62 x 15.5 mm

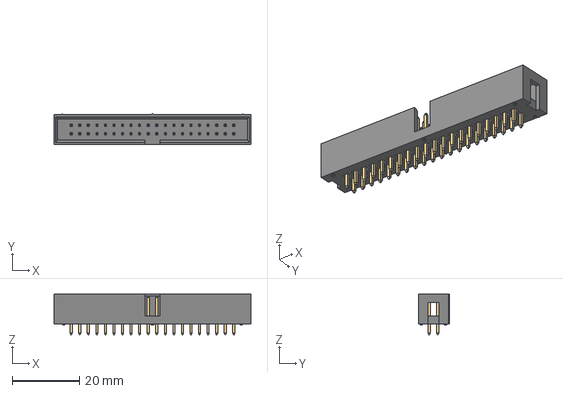
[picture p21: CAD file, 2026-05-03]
Models/61204021621.step
58.5 x 9.18 x 12.1 mm
6120xx21621_PIN x 40

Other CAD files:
CAD/Bases/Corner.stl

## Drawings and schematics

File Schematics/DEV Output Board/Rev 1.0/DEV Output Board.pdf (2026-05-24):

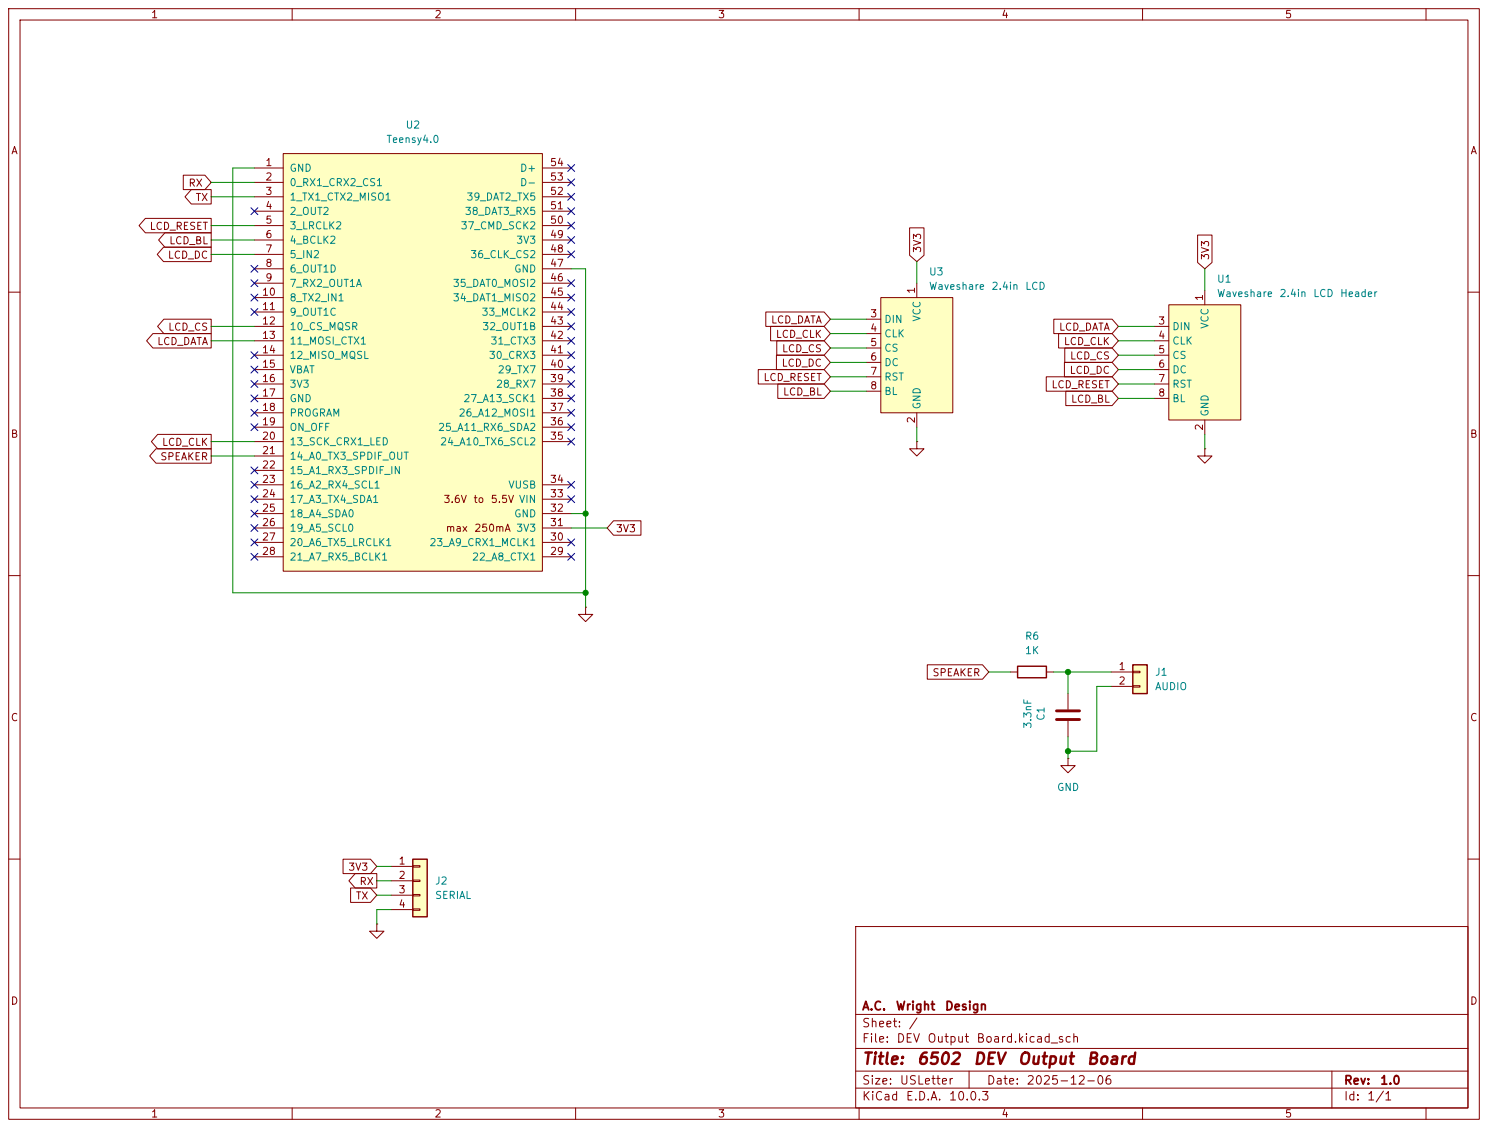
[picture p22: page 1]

2 DIN 3 CLK 4 CS 5 DC 6 RST 7 BL 8 U3Waveshare 2.4in LCD

Sheet: /
File: DEV Output Board.kicad_sch
Title: 6502 DEV Output Board

Size: USLetter | Rev: 1.0
KiCad E.D.A. 10.0.3 | Id: 1/1

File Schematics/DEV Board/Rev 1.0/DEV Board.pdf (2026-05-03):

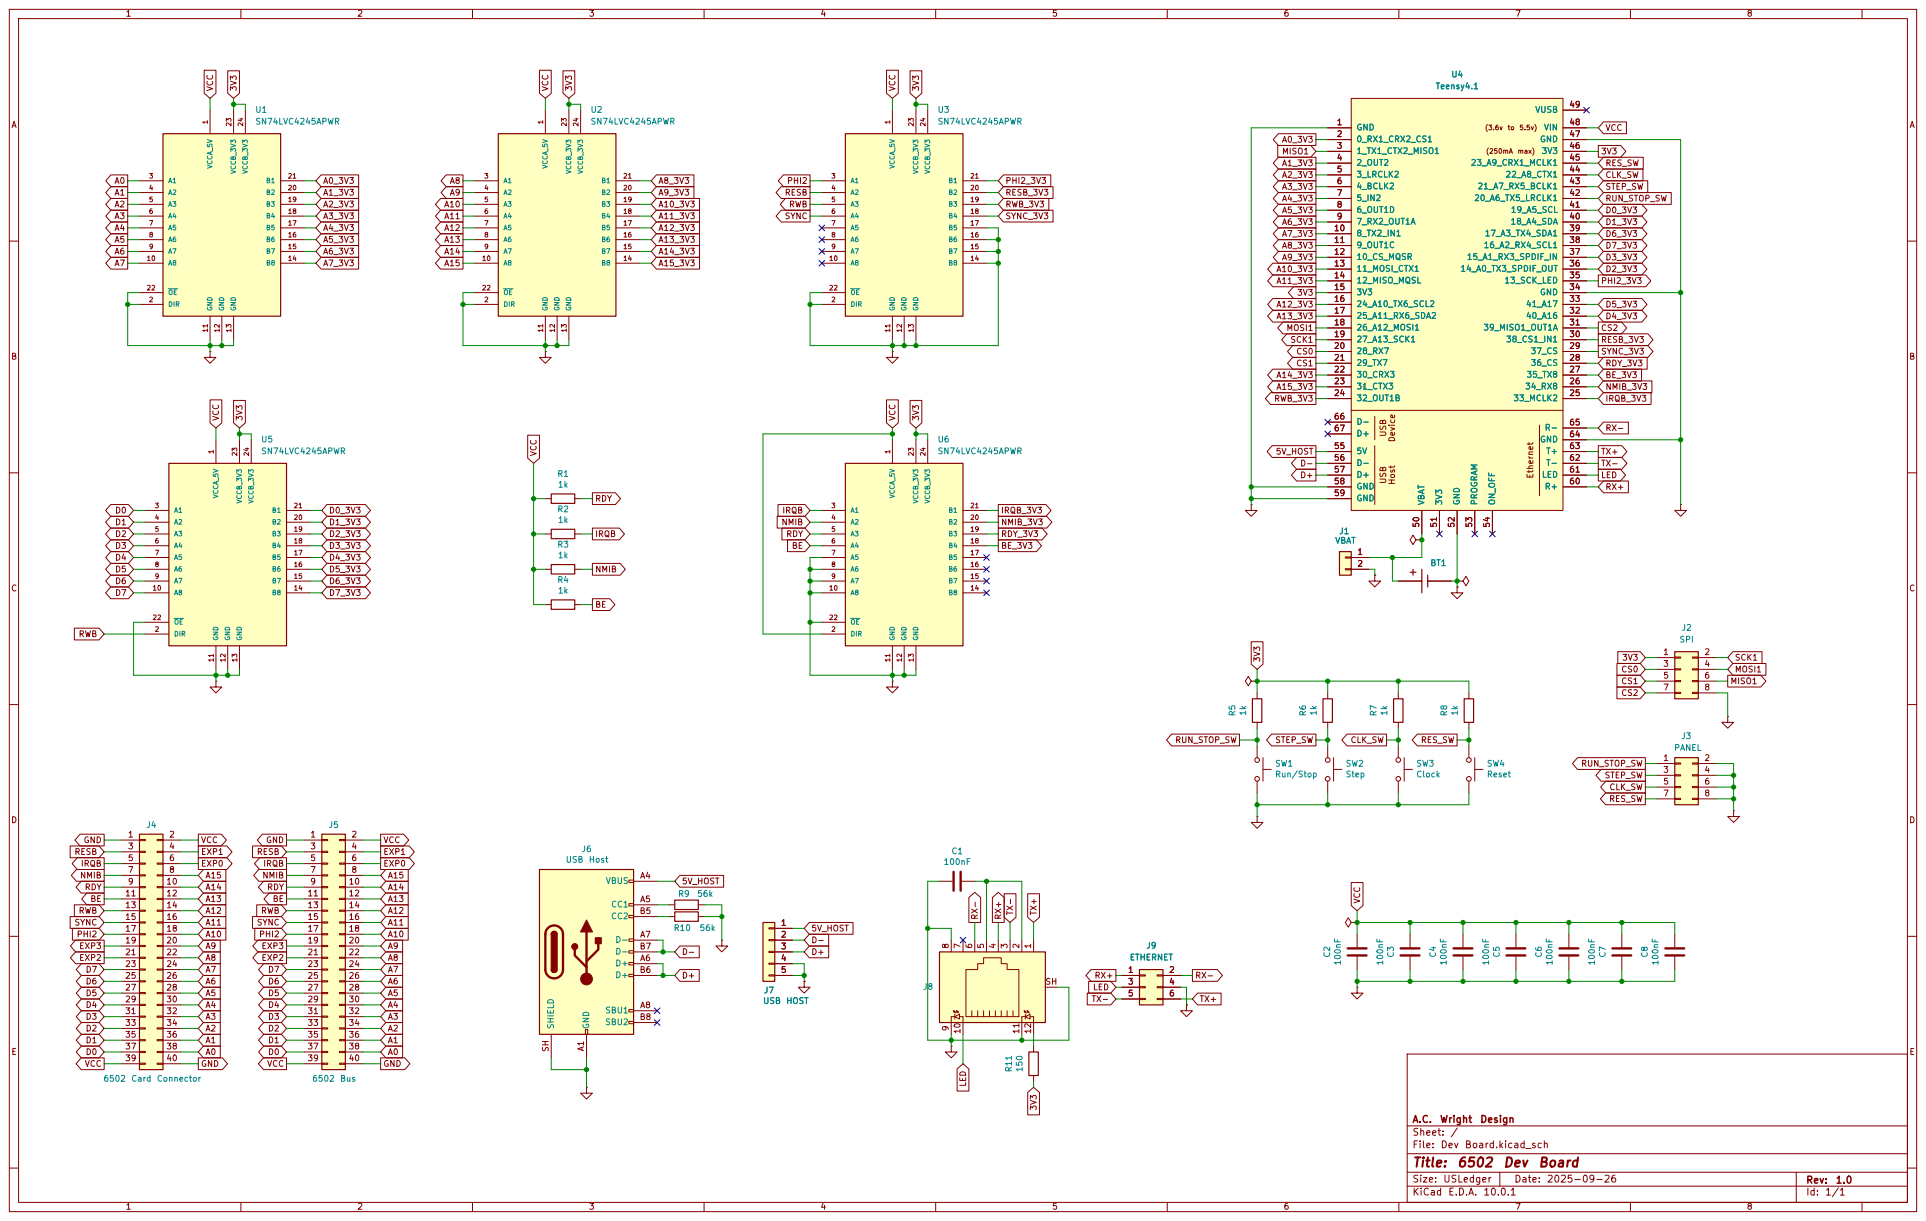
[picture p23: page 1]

Size: USLedger | Rev: 1.0
KiCad E.D.A. 10.0.1 | Id: 1/1

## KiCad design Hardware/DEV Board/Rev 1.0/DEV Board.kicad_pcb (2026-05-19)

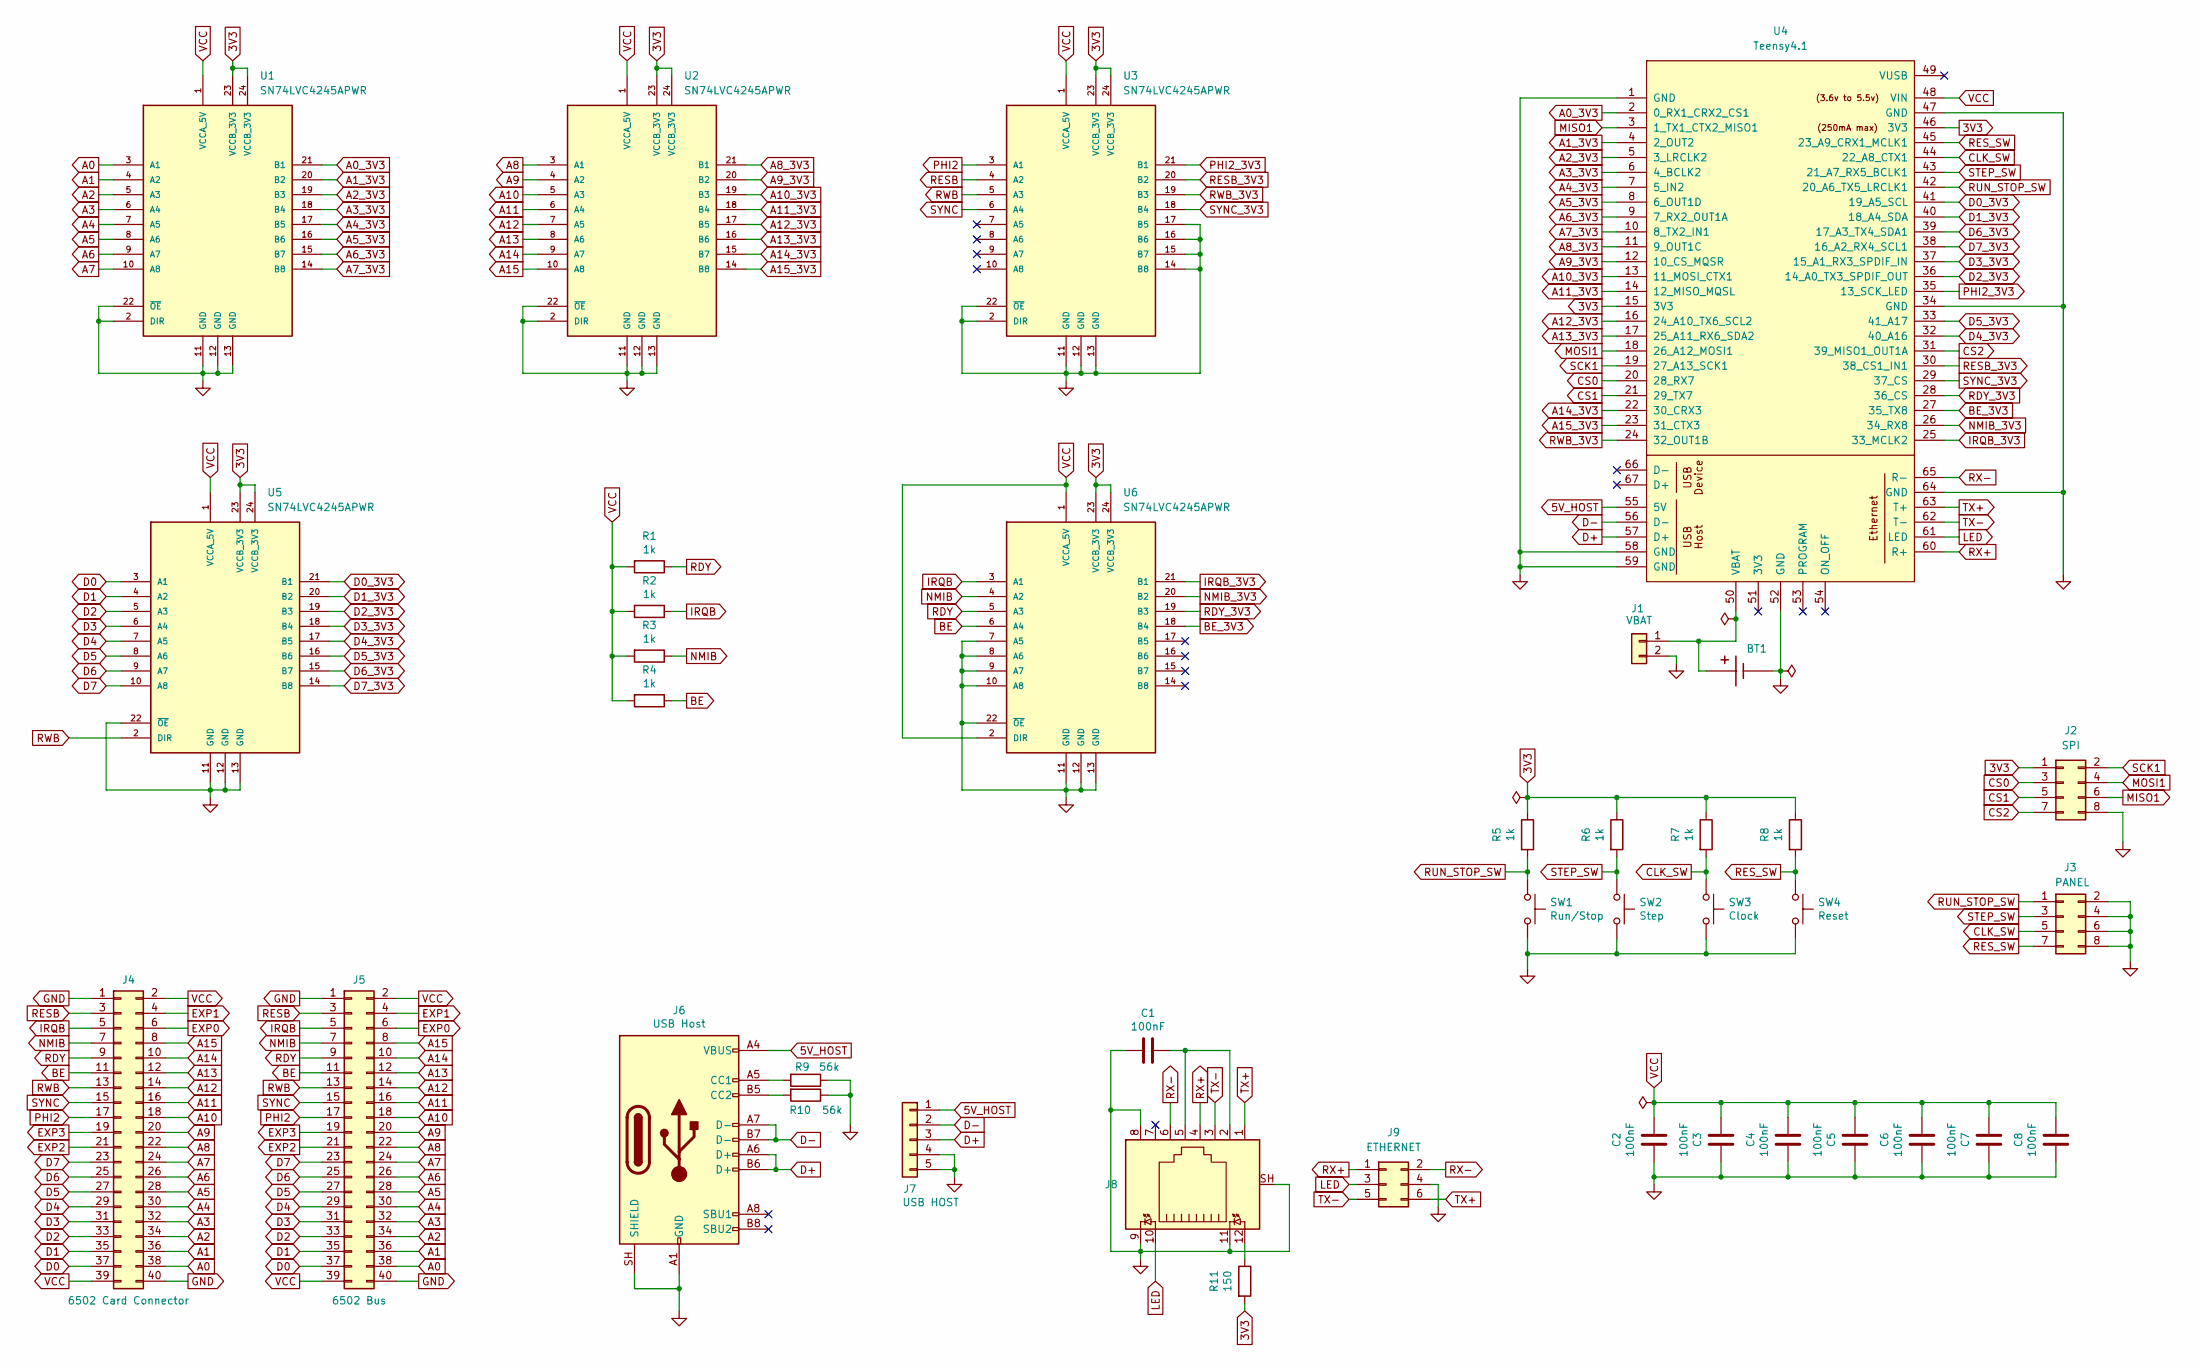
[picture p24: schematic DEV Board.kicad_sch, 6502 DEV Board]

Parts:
BT1: CR2032; BAT_BAT-HLD-001-THM; Digikey BAT-HLD-001-THM-ND
C1, C2, C3, C4, C5, C6, C7, C8: 100nF; C_0805_2012Metric; LCSC C49678
J1: VBAT; PinHeader_1x02_P2.54mm_Vertical
J2: SPI; PinHeader_2x04_P2.54mm_Vertical
J3: PANEL; PinHeader_2x04_P2.54mm_Vertical
J4: 6502 Card Connector; RHDR40W82P485X254_2X20_5740X93; Digikey A31723-ND
J5: 6502 Bus; 6502 Bus Connector
J6: USB Host; USB_C_Receptacle_HRO_TYPE-C-31-M-12; LCSC C2988369
J7: USB HOST; PinHeader_1x05_P2.54mm_Vertical
J8: RJ45_LED; J1B1211CCD; MPN J1B1211CCD; Digikey 1278-1052-ND
J9: ETHERNET; PinHeader_2x03_P2.00mm_Vertical
R1, R2, R3, R4, R5, R6, R7, R8: 1k; R_0805_2012Metric; LCSC C17513
R9, R10: 56k; R_0805_2012Metric; LCSC C169923
R11: 150; R_0805_2012Metric; LCSC C17471
SW1: Run/Stop; SW_TS-1187A-B-A-B; LCSC C318884
SW2: Step; SW_TS-1187A-B-A-B; LCSC C318884
SW3: Clock; SW_TS-1187A-B-A-B; LCSC C318884
SW4: Reset; SW_TS-1187A-B-A-B; LCSC C318884
U1, U2, U3, U5, U6: SN74LVC4245APWR; TSSOP-24_4.4x7.8mm_P0.65mm; LCSC C7859
U4: Teensy4.1; Teensy41

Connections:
3V3: J2.1, R5.1, R6.1, R7.1, R8.1, R11.2, U1.23 (VCCB_3V3), U1.24 (VCCB_3V3), U2.23 (VCCB_3V3), U2.24 (VCCB_3V3), U3.23 (VCCB_3V3), U3.24 (VCCB_3V3), U4.15 (3V3), U4.46 (3V3), U5.23 (VCCB_3V3), U5.24 (VCCB_3V3), U6.23 (VCCB_3V3), U6.24 (VCCB_3V3)
5V_HOST: J6.A4 (VBUS), J6.A9 (VBUS), J6.B4 (VBUS), J6.B9 (VBUS), J7.1, U4.55 (5V)
A0: J4.38, J5.38, U1.3 (A1)
A0_3V3: U1.21 (B1), U4.2 (0_RX1_CRX2_CS1)
A1: J4.36, J5.36, U1.4 (A2)
A1_3V3: U1.20 (B2), U4.4 (2_OUT2)
A2: J4.34, J5.34, U1.5 (A3)
A2_3V3: U1.19 (B3), U4.5 (3_LRCLK2)
A3: J4.32, J5.32, U1.6 (A4)
A3_3V3: U1.18 (B4), U4.6 (4_BCLK2)
A4: J4.30, J5.30, U1.7 (A5)
A4_3V3: U1.17 (B5), U4.7 (5_IN2)
A5: J4.28, J5.28, U1.8 (A6)
A5_3V3: U1.16 (B6), U4.8 (6_OUT1D)
A6: J4.26, J5.26, U1.9 (A7)
A6_3V3: U1.15 (B7), U4.9 (7_RX2_OUT1A)
A7: J4.24, J5.24, U1.10 (A8)
A7_3V3: U1.14 (B8), U4.10 (8_TX2_IN1)
A8: J4.22, J5.22, U2.3 (A1)
A8_3V3: U2.21 (B1), U4.11 (9_OUT1C)
A9: J4.20, J5.20, U2.4 (A2)
A9_3V3: U2.20 (B2), U4.12 (10_CS_MQSR)
A10: J4.18, J5.18, U2.5 (A3)
A10_3V3: U2.19 (B3), U4.13 (11_MOSI_CTX1)
A11: J4.16, J5.16, U2.6 (A4)
A11_3V3: U2.18 (B4), U4.14 (12_MISO_MQSL)
A12: J4.14, J5.14, U2.7 (A5)
A12_3V3: U2.17 (B5), U4.16 (24_A10_TX6_SCL2)
A13: J4.12, J5.12, U2.8 (A6)
A13_3V3: U2.16 (B6), U4.17 (25_A11_RX6_SDA2)
A14: J4.10, J5.10, U2.9 (A7)
A14_3V3: U2.15 (B7), U4.22 (30_CRX3)
A15: J4.8, J5.8, U2.10 (A8)
A15_3V3: U2.14 (B8), U4.23 (31_CTX3)
BE: J4.11, J5.11, R4.1, U6.6 (A4)
BE_3V3: U4.27 (35_TX8), U6.18 (B4)
CLK_SW: J3.5, R7.2, SW3.1, U4.44 (22_A8_CTX1)
CS0: J2.3, U4.20 (28_RX7)
CS1: J2.5, U4.21 (29_TX7)
CS2: J2.7, U4.31 (39_MISO1_OUT1A)
D0: J4.37, J5.37, U5.3 (A1)
D0_3V3: U4.41 (19_A5_SCL), U5.21 (B1)
D1: J4.35, J5.35, U5.4 (A2)
D1_3V3: U4.40 (18_A4_SDA), U5.20 (B2)
D2: J4.33, J5.33, U5.5 (A3)
D2_3V3: U4.36 (14_A0_TX3_SPDIF_OUT), U5.19 (B3)
D3: J4.31, J5.31, U5.6 (A4)
D3_3V3: U4.37 (15_A1_RX3_SPDIF_IN), U5.18 (B4)
D4: J4.29, J5.29, U5.7 (A5)
D4_3V3: U4.32 (40_A16), U5.17 (B5)
D5: J4.27, J5.27, U5.8 (A6)
D5_3V3: U4.33 (41_A17), U5.16 (B6)
D6: J4.25, J5.25, U5.9 (A7)
D6_3V3: U4.39 (17_A3_TX4_SDA1), U5.15 (B7)
D7: J4.23, J5.23, U5.10 (A8)
D7_3V3: U4.38 (16_A2_RX4_SCL1), U5.14 (B8)
D+: J6.A6 (D+), J6.B6 (D+), J7.3, U4.57 (D+)
D-: J6.A7 (D-), J6.B7 (D-), J7.2, U4.56 (D-)
EXP0: J4.6, J5.6
EXP1: J4.4, J5.4
EXP2: J4.21, J5.21
EXP3: J4.19, J5.19
GND: BT1.-, C1.2, C2.2, C3.1, C4.2, C5.1, C6.2, C7.1, C8.2, J1.2, J2.8, J3.2, J3.4, J3.6, J3.8, J4.1, J4.40, J5.1, J5.40, J6.A1 (GND), J6.A12 (GND), J6.B1 (GND), J6.B12 (GND), J6.SH (SHIELD), J7.4, J7.5, J8.8, J8.9, J8.11, J8.SH, J9.4, R9.1, R10.1, SW1.2, SW2.2, SW3.2, SW4.2, U1.2 (DIR), U1.11 (GND), U1.12 (GND), U1.13 (GND), U1.22 (~OE), U2.2 (DIR), U2.11 (GND), U2.12 (GND), U2.13 (GND), U2.22 (~OE), U3.2 (DIR), U3.11 (GND), U3.12 (GND), U3.13 (GND), U3.14 (B8), U3.15 (B7), U3.16 (B6), U3.17 (B5), U3.22 (~OE), U4.1 (GND), U4.34 (GND), U4.47 (GND), U4.52 (GND), U4.58 (GND), U4.59 (GND), U4.64 (GND), U5.11 (GND), U5.12 (GND), U5.13 (GND), U5.22 (~OE), U6.7 (A5), U6.8 (A6), U6.9 (A7), U6.10 (A8), U6.11 (GND), U6.12 (GND), U6.13 (GND), U6.22 (~OE)
IRQB: J4.5, J5.5, R2.1, U6.3 (A1)
IRQB_3V3: U4.25 (33_MCLK2), U6.21 (B1)
LED: J8.10, J9.3, U4.61 (LED)
MISO1: J2.6, U4.3 (1_TX1_CTX2_MISO1)
MOSI1: J2.4, U4.18 (26_A12_MOSI1)
NMIB: J4.7, J5.7, R3.1, U6.4 (A2)
NMIB_3V3: U4.26 (34_RX8), U6.20 (B2)
unnamed: C1.1, J8.2, J8.5
unnamed: BT1.+, J1.1, U4.50 (VBAT)
unnamed: J6.A5 (CC1), R9.2
unnamed: J6.B5 (CC2), R10.2
unnamed: J8.12, R11.1
PHI2: J4.17, J5.17, U3.3 (A1)
PHI2_3V3: U3.21 (B1), U4.35 (13_SCK_LED)
RDY: J4.9, J5.9, R1.1, U6.5 (A3)
RDY_3V3: U4.28 (36_CS), U6.19 (B3)
RESB: J4.3, J5.3, U3.4 (A2)
RESB_3V3: U3.20 (B2), U4.30 (38_CS1_IN1)
RES_SW: J3.7, R8.2, SW4.1, U4.45 (23_A9_CRX1_MCLK1)
RUN_STOP_SW: J3.1, R5.2, SW1.1, U4.42 (20_A6_TX5_LRCLK1)
RWB: J4.13, J5.13, U3.5 (A3), U5.2 (DIR)
RWB_3V3: U3.19 (B3), U4.24 (32_OUT1B)
RX+: J8.4, J9.1, U4.60 (R+)
RX-: J8.6, J9.2, U4.65 (R-)
SCK1: J2.2, U4.19 (27_A13_SCK1)
STEP_SW: J3.3, R6.2, SW2.1, U4.43 (21_A7_RX5_BCLK1)
SYNC: J4.15, J5.15, U3.6 (A4)
SYNC_3V3: U3.18 (B4), U4.29 (37_CS)
TX+: J8.1, J9.6, U4.63 (T+)
TX-: J8.3, J9.5, U4.62 (T-)
VCC: C2.1, C3.2, C4.1, C5.2, C6.1, C7.2, C8.1, J4.2, J4.39, J5.2, J5.39, R1.2, R2.2, R3.2, R4.2, U1.1 (VCCA_5V), U2.1 (VCCA_5V), U3.1 (VCCA_5V), U4.48 (VIN), U5.1 (VCCA_5V), U6.1 (VCCA_5V), U6.2 (DIR)

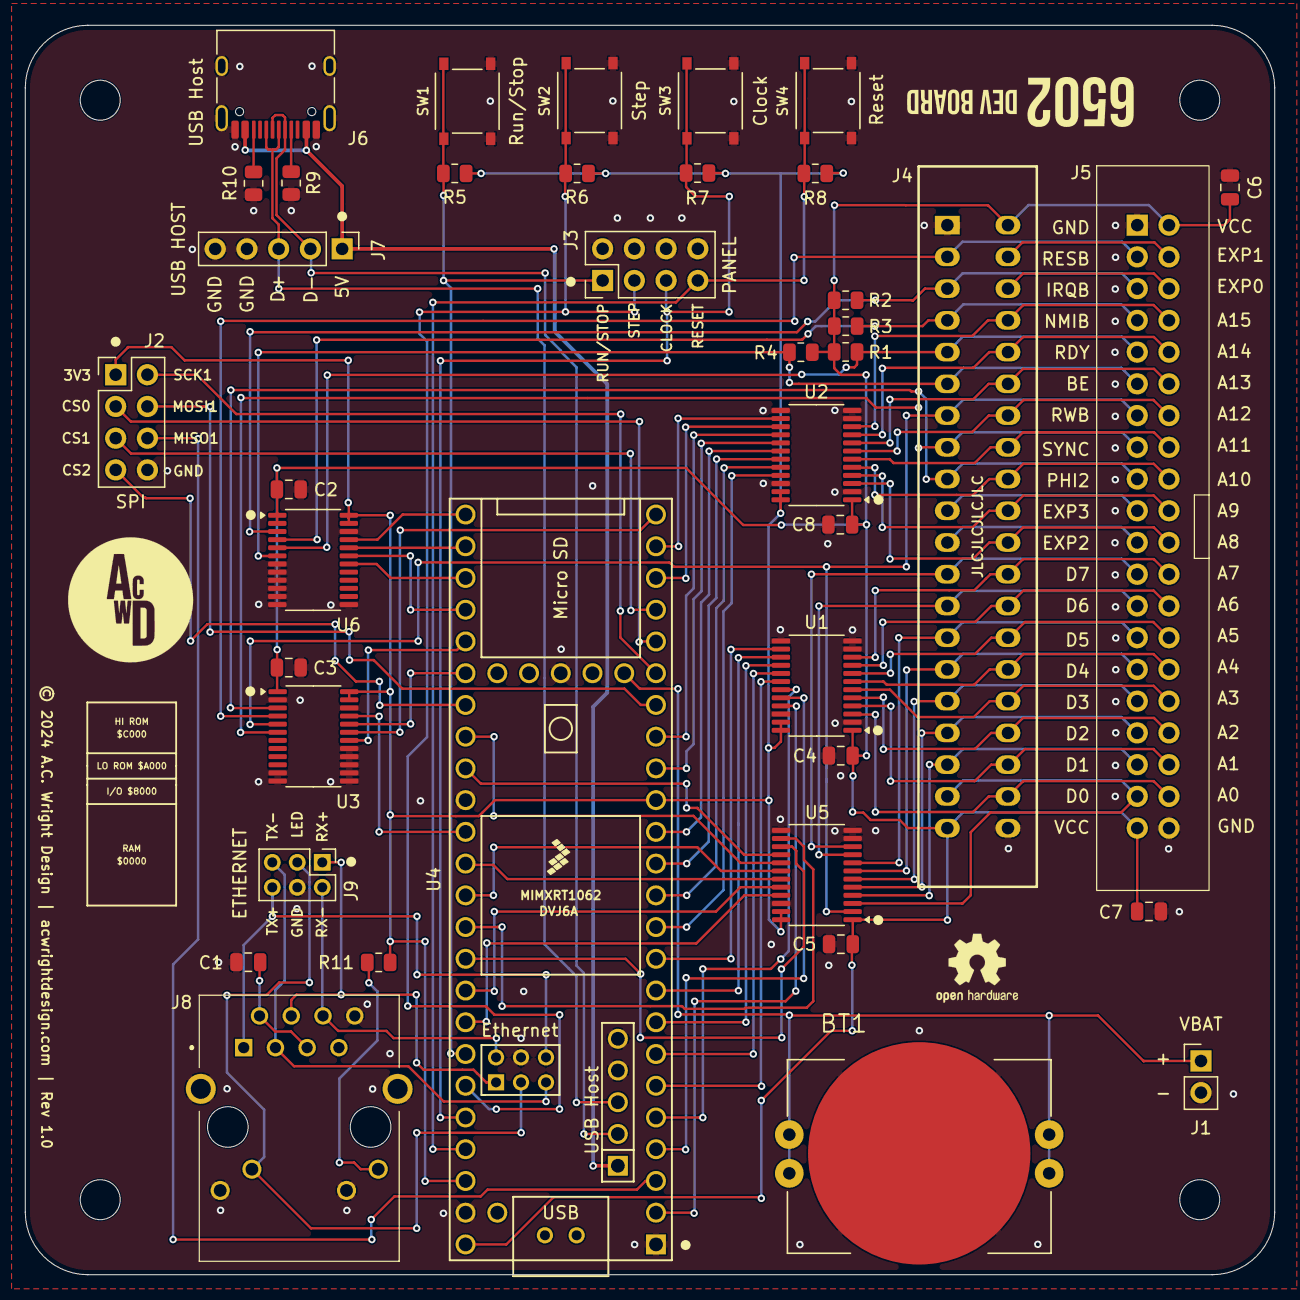
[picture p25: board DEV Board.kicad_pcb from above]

Board: 2 copper layers, 100.0 x 100.0 mm, 43 parts (0 on the bottom side), 94 nets.

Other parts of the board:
H1, H2, H3, H4: MountingHole; MountingHole_3.2mm_M3

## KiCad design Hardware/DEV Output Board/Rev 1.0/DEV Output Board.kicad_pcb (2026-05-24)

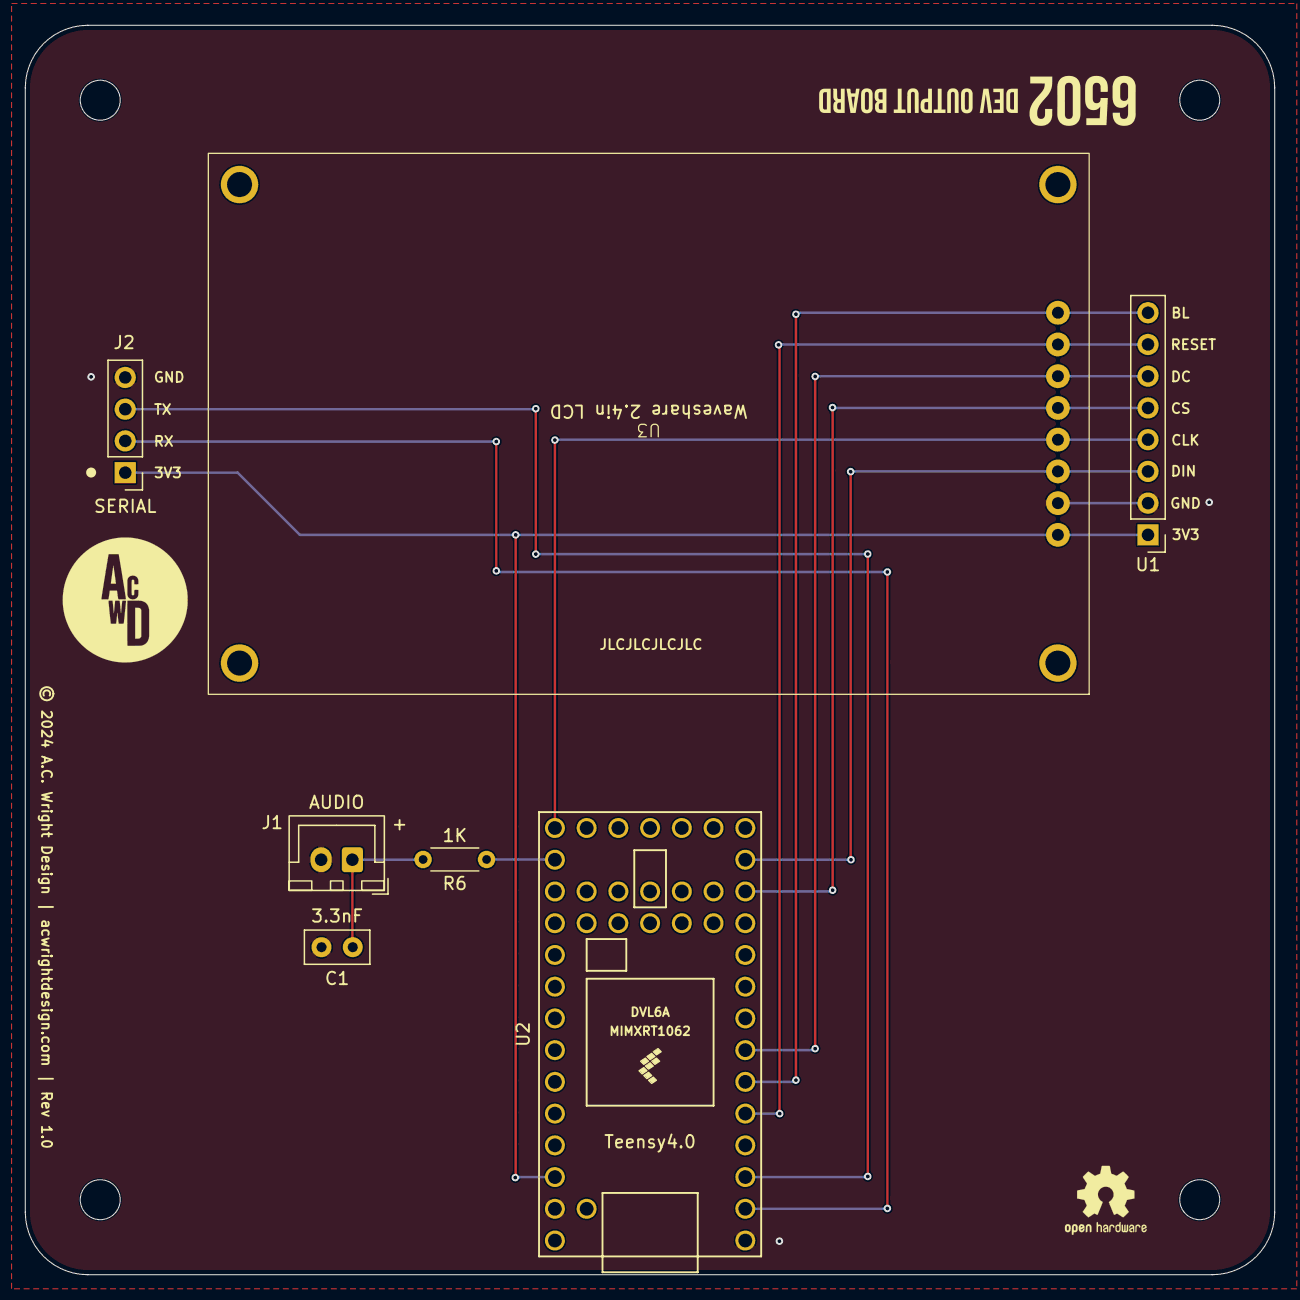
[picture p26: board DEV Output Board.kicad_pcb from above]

Board: 2 copper layers, 100.0 x 100.0 mm, 11 parts (0 on the bottom side), 12 nets.

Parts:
C1: 3.3nF; C_Disc_D5.0mm_W2.5mm_P2.50mm
H1, H2, H3, H4: MountingHole; MountingHole_3.2mm_M3
J1: AUDIO; JST_XH_B2B-XH-A_1x02_P2.50mm_Vertical
J2: SERIAL; PinHeader_1x04_P2.54mm_Vertical
R6: 1K; R_Axial_DIN0204_L3.6mm_D1.6mm_P5.08mm_Horizontal
U1: Waveshare 2.4in LCD Header; PinHeader_1x08_P2.54mm_Vertical
U2: Teensy4.0; Teensy40
U3: Waveshare 2.4in LCD

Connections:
3V3: J2.1, U1.1 (VCC), U2.31 (3V3), U3.1 (VCC)
GND: C1.2, J1.2, J2.4, U1.2 (GND), U2.1 (GND), U2.32 (GND), U3.2 (GND)
LCD_BL: U1.8 (BL), U2.6 (4_BCLK2), U3.8 (BL)
LCD_CLK: U1.4 (CLK), U2.20 (13_SCK_CRX1_LED), U3.4 (CLK)
LCD_CS: U1.5 (CS), U2.12 (10_CS_MQSR), U3.5 (CS)
LCD_DATA: U1.3 (DIN), U2.13 (11_MOSI_CTX1), U3.3 (DIN)
LCD_DC: U1.6 (DC), U2.7 (5_IN2), U3.6 (DC)
LCD_RESET: U1.7 (RST), U2.5 (3_LRCLK2), U3.7 (RST)
unnamed: C1.1, J1.1, R6.2
RX: J2.2, U2.2 (0_RX1_CRX2_CS1)
SPEAKER: R6.1, U2.21 (14_A0_TX3_SPDIF_OUT)
TX: J2.3, U2.3 (1_TX1_CTX2_MISO1)

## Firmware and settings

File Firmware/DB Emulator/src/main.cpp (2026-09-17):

#include <Arduino.h>
#include <ArduinoJson.h>
#include <TimeLib.h>
#include <Bounce2.h>
#include <SD.h>
#include <EEPROM.h>
#include <USBHost_t36.h>
#include <QNEthernet.h>
#include <AsyncWebServer_Teensy41.h>
#include <6502.h>

using namespace qindesign::network;

Button clkButton      = Button();
Button stepButton     = Button();
Button runStopButton  = Button();
#ifdef DEVBOARD_1
Button resetButton    = Button();
#endif

USBHost             usb;
USBHub              hub1(usb);
USBHIDParser        hid1(usb);
USBHIDParser        hid2(usb);
USBHIDParser        hid3(usb);

KeyboardController  keyboard(usb);
JoystickController  joystick(usb);

EthernetClient      ethClient;
AsyncWebServer      server(80);

void onCommand(char command);
void onNumeric(uint8_t num);
void onKeyDown(uint8_t keycode);
void onKeyUp(uint8_t keycode);
void onJoystick();

void info();
void log();
void reset();
void tick();
void step();
void dump();
void snapshot();
void decreaseFrequency();
void increaseFrequency();
void toggleRunStop();
void unloadCart();
void readROMs();
void listROMs();
void loadROM(uint index);
void loadROMFile(String filename);
void loadROMPath(String path);
void readCarts();
void listCarts();
void loadCart(uint index);
void loadCartFile(String filename);
void loadCartPath(String path);
void readPrograms();
void listPrograms();
void loadProgram(uint index);
void loadProgramFile(String filename);
void loadProgramPath(String path);
void listFiles();
void prevPage();
void nextPage();

uint8_t read(uint16_t addr, bool isDbg);
void write(uint16_t addr, uint8_t val);

void initPins();
void initButtons();
void initSD();
void initUSB();
void initEthernet();
void initServer();
void initFiles();
void initWWWCache();

void buildMemoryMap();

void startCpuTimer();
void stopCpuTimer();
void cpuTimerISR();

time_t syncTime();
String formattedDateTime();
time_t lastSnapshot;

void onServerRoot(AsyncWebServerRequest *request);
void onServerInfo(AsyncWebServerRequest *request);
void onServerMemory(AsyncWebServerRequest *request);
void onServerStorage(AsyncWebServerRequest *request);
void onServerLoad(AsyncWebServerRequest *request);
void onServerControl(AsyncWebServerRequest *request);
void onServerKeyboard(AsyncWebServerRequest *request);
void onServerNotFound(AsyncWebServerRequest *request);

volatile uint8_t freqIndex = FREQ_SIZE - 1;
bool isRunning = false;
bool isStepping = false;
bool autoStart = false;
volatile bool cartLoaded = false;

uint8_t inputCtx = INPUT_CTX_ROM;

uint16_t address = 0;
uint8_t data = 0;
bool readWrite = HIGH;

String ROMs[FILE_MAX];
uint romFilePage = 0;
String Carts[FILE_MAX];
uint cartFilePage = 0;
String Programs[FILE_MAX];
uint programFilePage = 0;

uint memoryPage = 0;

#ifdef MEM_EXTMEM
EXTMEM __attribute__((aligned(32))) uint8_t ramData1[RC_BLOCK_SIZE * RC_BLOCK_COUNT];
EXTMEM __attribute__((aligned(32))) uint8_t ramData2[RC_BLOCK_SIZE * RC_BLOCK_COUNT];
#else
__attribute__((aligned(32))) uint8_t ramData1[RC_BLOCK_SIZE * RC_BLOCK_COUNT];
__attribute__((aligned(32))) uint8_t ramData2[RC_BLOCK_SIZE * RC_BLOCK_COUNT];
#endif

static uint32_t cachedCpuFrequency = 1000000;
static uint8_t cachedCpuFreqIndex = 0xFF;

IntervalTimer cpuTimer;
volatile bool timerMode = false;
volatile uint8_t busPhase = 0;

// Use IntervalTimer for slow frequencies where blocking delays would freeze loop().
// At period >= TIMER_FREQ_THRESHOLD (µs), the ISR completes well within each half-cycle.
// Above that frequency, tight-loop with inline delays is used (loop() stays responsive).
#define TIMER_FREQ_THRESHOLD 32

enum MemoryRegion : uint8_t {
  REGION_CART_CODE,
  REGION_ROM,
  REGION_RAM,
  REGION_IO,
  REGION_NONE
};
static MemoryRegion memoryMap[256]; // 256 possible high bytes

CPU cpu = CPU(read, write);
RAM ram = RAM();
ROM rom = ROM();
Cart cart = Cart();

RAMCard ramCard1 = RAMCard(ramData1);
RAMCard ramCard2 = RAMCard(ramData2);
RTCCard rtcCard = RTCCard();
StorageCard storageCard = StorageCard();
SerialCard serialCard = SerialCard();
GPIOCard gpioCard = GPIOCard();
SoundCard soundCard = SoundCard();
VideoCard videoCard = VideoCard();

// GPIO Attachments
GPIOKeyboardMatrixAttachment keyboardMatrixAttachment = GPIOKeyboardMatrixAttachment(10);     // Priority 10
GPIOKeyboardEncoderAttachment keyboardEncoderAttachment = GPIOKeyboardEncoderAttachment(20);  // Priority 20 (supports both Port A and B)
GPIOJoystickAttachment joystickAttachmentA = GPIOJoystickAttachment(true, 100);              // Port A, Priority 100
GPIOJoystickAttachment joystickAttachmentB = GPIOJoystickAttachment(false, 100);              // Port B, Priority 100

//
// MAIN
//

void setup() {
  Serial.begin(115200);       // Ignored by Teensy; Baud rate is USB data rate 480Mbps
  SerialUSB1.begin(115200);   // Ignored by Teensy; Baud rate is USB data rate 480Mbps
  SerialUSB2.begin(115200);   // Ignored by Teensy; Baud rate is USB data rate 480Mbps
  HWSERIAL.begin(6000000);    // 6 Mbit/sec — maximum on Teensy 4.1 without clock reconfiguration
  static uint8_t hwSerialWriteBuffer[8192];
  HWSERIAL.addMemoryForWrite(hwSerialWriteBuffer, sizeof(hwSerialWriteBuffer));

  setSyncProvider(syncTime);
  buildMemoryMap();
  
  // Attach peripherals to GPIO Card
  // Keyboard matrix (manual scanning) - highest priority for Port A rows
  gpioCard.attachToPortA(&keyboardMatrixAttachment);
  gpioCard.attachToPortB(&keyboardMatrixAttachment);
  
  // Keyboard encoder (ASCII on both Port A and Port B) - medium priority
  gpioCard.attachToPortA(&keyboardEncoderAttachment);
  gpioCard.attachToPortB(&keyboardEncoderAttachment);
  
  // Joystick (Port A and Port B) - lowest priority, fallback
  gpioCard.attachToPortA(&joystickAttachmentA);
  gpioCard.attachToPortB(&joystickAttachmentB);
  
  initPins();
  initButtons();
  initSD();
  initWWWCache();
  initUSB();
  initEthernet();
  initServer();
  initFiles();

  readROMs();
  readCarts();
  readPrograms();

  info();

  if (autoStart) {
    delay(500);
    reset();
    toggleRunStop();
  }
}

void loop() {
  usb.Task();

  clkButton.update();
  stepButton.update();
  runStopButton.update();
#ifdef DEVBOARD_1
  resetButton.update();
#endif

  if (clkButton.pressed()) {
    decreaseFrequency();
  }
  if (stepButton.pressed()) {
    step();
  }
  if (runStopButton.pressed()) {
    toggleRunStop();
  }
#ifdef DEVBOARD_1
  if (resetButton.pressed()) {
    reset();
  }
#endif

  if (joystick.available()) {
    onJoystick();
  }
  if (Serial.available()) {
    onCommand(Serial.read());
  }

  if (isRunning && !timerMode) {
    // Batch multiple ticks per loop() iteration to amortize USB/button overhead.
    // At 1MHz each tick is ~0.3-0.5µs on Cortex-M7; 512 ticks ≈ 150-250µs per batch,
    // leaving loop() responsive at ~4000 iterations/sec for USB and input polling.
    for (uint16_t i = 0; i < 2048; i++) {
      tick();
    }
  }
}

//
// EVENTS
//

void onCommand(char command) {
  switch (command) {
    case '0':
    case '1':
    case '2':
    case '3':
    case '4':
    case '5':
    case '6':
    case '7': {
      if (!SD.mediaPresent()) { Serial.println("SD Card Not Detected!"); break; }
      uint8_t index = String(command).toInt();
      onNumeric(index);
      switch(inputCtx) {
        case INPUT_CTX_ROM:
          Serial.print("Loaded ROM: ");
          Serial.println(rom.file);
          break;
        case INPUT_CTX_CART:
          Serial.print("Loaded Cart: ");
          Serial.println(cart.file);
          break;
        case INPUT_CTX_PROG:
          Serial.print("Loaded Program: ");
          Serial.println(ram.file);
          break;
        case INPUT_CTX_MEM:
          break;
        default:
          break;
      }
      break;
    }
    case 'a':
    case 'A':
      if (!SD.mediaPresent()) { Serial.println("SD Card Not Detected!"); break; }
      readPrograms();
      listPrograms();
      break;
    case 'c':
    case 'C':
      if (!SD.mediaPresent()) { Serial.println("SD Card Not Detected!"); break; }
      readCarts();
      listCarts();
      break;
    case 'd':
    case 'D':
      dump();
      break;
    case 'f':
    case 'F':
      info();
      break;
    case 'g':
    case 'G':
      log();
      break;
    case 'k':
    case 'K':
      tick();
      log();
      break;

    case 'm':
    case 'M':
      if (!SD.mediaPresent()) { Serial.println("SD Card Not Detected!"); break; }
      readROMs();
      listROMs();
      break;

    case 'p':
    case 'P':
      if (!SD.mediaPresent()) { Serial.println("SD Card Not Detected!"); break; }
      Serial.print("Creating snapshot... ");
      snapshot();
      Serial.print("Success! (");
      Serial.print(lastSnapshot);
      Serial.println(")");
      break;
    case 'r':
    case 'R':
      toggleRunStop();
      Serial.println(isRunning ? "Running…" : "Stopped");
      break;
    case 's':
    case 'S':
      if (!isRunning) {
        step();
        log();
      } else {
        Serial.println("Clock must be stopped before stepping!");
      }
      break;
    case 't':
    case 'T':
      Serial.print("Resetting... ");
      reset();
      Serial.println("Done");
      break;
    case 'u':
    case 'U':
      unloadCart();
      Serial.print("Cart: ");
      Serial.println(cart.file);
      break;
    case '-':
      decreaseFrequency();
      Serial.print("Frequency: ");
      Serial.println(FREQ_LABELS[freqIndex]);
      break;
    case '+':
      increaseFrequency();
      Serial.print("Frequency: ");
      Serial.println(FREQ_LABELS[freqIndex]);
      break;
    case '[':
      switch(inputCtx) {
        case INPUT_CTX_MEM:
          prevPage();
          dump();
          break;
        default:          
          prevPage();
          listFiles();
          break;
      }
      break;
    case ']':
      switch(inputCtx) {
        case INPUT_CTX_MEM:
          nextPage();
          dump();
          break;
        default:          
          nextPage();
          listFiles();
          break;
      }
      break;
  }
}

void onNumeric(uint8_t num) {
  switch(inputCtx) {
    case INPUT_CTX_ROM:
      loadROM(num);
      break;
    case INPUT_CTX_CART:
      loadCart(num);
      break;
    case INPUT_CTX_PROG:
      loadProgram(num);
      break;
    case INPUT_CTX_MEM:
      break;
  }
}

void onKeyDown(uint8_t keycode) {
  // Fix some quirks in the USBHost_t36 library
  // Remapped following this: https://gist.github.com/MightyPork/6da26e382a7ad91b5496ee55fdc73db2
  switch (keycode) {
    case 0x67: // LEFT CTRL
      keycode = 0xE0;
      break;
    case 0x68: // LEFT SHIFT
      keycode = 0xE1;
      break;
    case 0x69: // LEFT ALT
      keycode = 0xE2;
      break;
    case 0x6A: // LEFT META
      keycode = 0xE3;
      break;
    case 0x6B: // RIGHT CTRL
      keycode = 0xE4;
      break;
    case 0x6C: // RIGHT SHIFT
      keycode = 0xE5;
      break;
    case 0x6D: // RIGHT ALT
      keycode = 0xE6;
      break;
    case 0x6E: // RIGHT META
      keycode = 0xE7;
      break;
    default:
      break;
  }

  // Route keyboard input to attachments
  keyboardMatrixAttachment.updateKey(keycode, true);      // Update keyboard matrix
  keyboardEncoderAttachment.updateKeyPortB(keycode, true); // USB/browser keyboard → Port B (matrix encoder)
  
  #ifdef KEYBOARD_DEBUG
  Serial.print("Key pressed: 0x");
  Serial.println(keycode, HEX);
  Serial.println(keycode);
  #endif
}

void onKeyUp(uint8_t keycode) {
  // Fix some quirks in the USBHost_t36 library
  // Remapped following this: https://gist.github.com/MightyPork/6da26e382a7ad91b5496ee55fdc73db2
  switch (keycode) {
    case 0x67: // LEFT CTRL
      keycode = 0xE0;
      break;
    case 0x68: // LEFT SHIFT
      keycode = 0xE1;
      break;
    case 0x69: // LEFT ALT
      keycode = 0xE2;
      break;
    case 0x6A: // LEFT META
      keycode = 0xE3;
      break;
    case 0x6B: // RIGHT CTRL
      keycode = 0xE4;
      break;
    case 0x6C: // RIGHT SHIFT
      keycode = 0xE5;
      break;
    case 0x6D: // RIGHT ALT
      keycode = 0xE6;
      break;
    case 0x6E: // RIGHT META
      keycode = 0xE7;
      break;
    default:
      break;
  }

  // Release key from keyboard matrix
  keyboardMatrixAttachment.updateKey(keycode, false);       // Update keyboard matrix
  keyboardEncoderAttachment.updateKeyPortB(keycode, false); // USB/browser keyboard → Port B (matrix encoder)
  
  #ifdef KEYBOARD_DEBUG
  Serial.print("Key Released: 0x");
  Serial.println(keycode, HEX);
  Serial.println(keycode);
  #endif
}

void onJoystick() {
  uint32_t buttons = joystick.getButtons();
  
  if (joystick.joystickType() == JoystickController::XBOX360 || 
      joystick.joystickType() == JoystickController::XBOXONE) 
  {
    // Map Xbox controller to 8-bit joystick format
    // Xbox button layout: bit 0=A, 1=B, 2=X, 3=Y, 4=LB, 5=RB, 6=Back, 7=Start, etc.
    // DB Joystick: bit 0=A, 1=B, 2=X, 3=Y, 4=U, 5=D, 6=L, 7=R
    
    uint8_t mappedButtons = 0;
    
    // Map face buttons (A, B, X, Y from Xbox to DB format)
    if (buttons & 0x0001) mappedButtons |= 0x01;  // Xbox A -> DB A (bit 0)
    if (buttons & 0x0002) mappedButtons |= 0x02;  // Xbox B -> DB B (bit 1)
    if (buttons & 0x0004) mappedButtons |= 0x04;  // Xbox X -> DB X (bit 2)
    if (buttons & 0x0008) mappedButtons |= 0x08;  // Xbox Y -> DB Y (bit 3)
    
    // Map D-Pad or analog stick to directions
    // Get analog stick positions for directional control
    int axisX = joystick.getAxis(0);  // Left stick X
    int axisY = joystick.getAxis(1);  // Left stick Y
    
    // Check D-Pad buttons (typically bits 12-15 on Xbox controllers)
    bool dpadUp    = (buttons & 0x0100) != 0;
    bool dpadDown  = (buttons & 0x0200) != 0;
    bool dpadLeft  = (buttons & 0x0400) != 0;
    bool dpadRight = (buttons & 0x0800) != 0;
    
    // Combine D-Pad and analog stick (analog stick uses threshold)
    const int analogThreshold = 128;  // Threshold for analog stick direction
    
    if (dpadUp || axisY < -analogThreshold)    mappedButtons |= 0x10;  // UP (bit 4)
    if (dpadDown || axisY > analogThreshold)   mappedButtons |= 0x20;  // DOWN (bit 5)
    if (dpadLeft || axisX < -analogThreshold)  mappedButtons |= 0x40;  // LEFT (bit 6)
    if (dpadRight || axisX > analogThreshold)  mappedButtons |= 0x80;  // RIGHT (bit 7)
    
    joystickAttachmentB.updateJoystick(mappedButtons);
    
    #ifdef JOYSTICK_DEBUG
    Serial.print("Joystick: Raw=0x");
    Serial.print(buttons, HEX);
    Serial.print(" Mapped=0x");
    Serial.print(mappedButtons, HEX);
    Serial.print(" X=");
    Serial.print(axisX);
    Serial.print(" Y=");
    Serial.println(axisY);
    #endif
  }

  joystick.joystickDataClear();
}

//
// METHODS
//

void info() {
  Serial.println();
  Serial.println("888888 888888     88888                                              ");                        
  Serial.println("8    8 8    8     8     eeeeeee e   e e     eeeee eeeee eeeee eeeee  ");
  Serial.println("8e   8 8eeee8ee   8eeee 8  8  8 8   8 8     8   8   8   8  88 8   8  ");
  Serial.println("88   8 88     8   88    8e 8  8 8e  8 8e    8eee8   8e  8   8 8eee8e ");
  Serial.println("88   8 88     8   88    88 8  8 88  8 88    88  8   88  8   8 88   8 ");
  Serial.println("88eee8 88eeeee8   88eee 88 8  8 88ee8 88eee 88  8   88  8eee8 88   8");
  Serial.println();
  Serial.print("DB Emulator | Version: ");
  Serial.print(VERSION);
  Serial.println();
  Serial.println("---------------------------------");
  Serial.println("| © 2024 A.C. Wright Design     |");
  Serial.println("---------------------------------");
  Serial.println();
  Serial.print("RAM: ");
  Serial.println(ram.file);
  Serial.print("ROM: ");
  Serial.println(rom.file);
  Serial.print("Cart: ");
  Serial.println(cart.file);
  Serial.print("Frequency: ");
  Serial.println(FREQ_LABELS[freqIndex]);
  Serial.print("IP Address: ");
  Serial.println(Ethernet.localIP());
  Serial.print("Date / Time: ");
  Serial.println(formattedDateTime());
  Serial.println();
  Serial.println("--------------------------------------------------------------");
  Serial.println("| (R)un / Stop       | (S)tep / Tic(K)     | Rese(T)         |");
  Serial.println("--------------------------------------------------------------");
  Serial.println("| (+/-) Clk Freq     | (D)ump / Sna(P)shot | In(F)o / Lo(G)  |");
  Serial.println("--------------------------------------------------------------");
  Serial.println("| Unload Cart (U)    | List RO(M)s / (C)arts / Progr(A)ms    |");
  Serial.println("--------------------------------------------------------------");
  Serial.println();
}

void log() {
  char output[128];

  sprintf(
    output, 
    "| %c%c%c%c%c%c%c%c%c%c%c%c%c%c%c%c | %c%c%c%c%c%c%c%c | 0x%04X | 0x%02X | %c |", 
    BYTE_TO_BINARY((address >> 8) & 0xFF),
    BYTE_TO_BINARY(address & 0xFF), 
    BYTE_TO_BINARY(data),
    address, 
    data, 
    readWrite ? 'R' : 'W'
  );

  Serial.println(output);
}

void reset() {
  bool isCurrentlyRunning = isRunning;

  if (isCurrentlyRunning) {
    toggleRunStop();
  }

  cpu.reset();

  // Every slot gets reset, not just the ones with visible state — an ACIA with
  // stuck status flags, a VIA holding the encoder-enable low or a storage card
  // stopped mid-transfer all survive a reset otherwise.
  // RAMCard::reset() is deliberately a no-op: a reset does not wipe memory, so
  // the banked RAM only clears on a power cycle (its constructor).
  ramCard1.reset();
  ramCard2.reset();
  rtcCard.reset();
  storageCard.reset();
  serialCard.reset();
  gpioCard.reset();
  soundCard.reset();
  videoCard.reset();

  if (isCurrentlyRunning) {
    toggleRunStop();
  }
}

FASTRUN void tick() {
  if (freqIndex != cachedCpuFreqIndex) {
    cachedCpuFrequency = (uint32_t)(1000000.0 / FREQ_PERIODS[freqIndex]);
    cachedCpuFreqIndex = freqIndex;
  }

  cpu.tick();

  // Tick only IO cards that do actual work
  uint8_t interrupt = 0x00;
  interrupt |= rtcCard.tick(cachedCpuFrequency);
  interrupt |= serialCard.tick(cachedCpuFrequency);
  interrupt |= gpioCard.tick(cachedCpuFrequency);
  interrupt |= soundCard.tick(cachedCpuFrequency);
  interrupt |= videoCard.tick(cachedCpuFrequency);

  if (interrupt & 0x40) { cpu.nmiTrigger(); }
  if (interrupt & 0x80) { cpu.irqTrigger(); }
  else { cpu.irqClear(); }
}

void startCpuTimer() {
  double period = FREQ_PERIODS[freqIndex];
  if (period >= TIMER_FREQ_THRESHOLD) {
    busPhase = 0;
    timerMode = true;
    cpuTimer.begin(cpuTimerISR, period / 2.0);
  } else {
    timerMode = false;
  }
}

void stopCpuTimer() {
  if (timerMode) {
    cpuTimer.end();
    timerMode = false;
  }
}

FASTRUN void cpuTimerISR() {
  if (busPhase == 0) {
    if (freqIndex != cachedCpuFreqIndex) {
      cachedCpuFrequency = (uint32_t)(1000000.0 / FREQ_PERIODS[freqIndex]);
      cachedCpuFreqIndex = freqIndex;
    }

    cpu.tick();

    // Tick only IO cards that do actual work
    uint8_t interrupt = 0x00;
    interrupt |= rtcCard.tick(cachedCpuFrequency);
    interrupt |= serialCard.tick(cachedCpuFrequency);
    interrupt |= gpioCard.tick(cachedCpuFrequency);
    interrupt |= soundCard.tick(cachedCpuFrequency);
    interrupt |= videoCard.tick(cachedCpuFrequency);

    if (interrupt & 0x40) { cpu.nmiTrigger(); }
    if (interrupt & 0x80) { cpu.irqTrigger(); }
    else { cpu.irqClear(); }

    busPhase = 1;
  } else {
    busPhase = 0;
  }
}

void step() {
  // Execute one complete instruction and handle ticks/interrupts
  uint8_t ticks = cpu.step();

  // Process interrupts for each tick of the instruction
  for(uint i = 0; i < ticks; i++) {
    uint8_t interrupt = 0x00;

    // Calculate CPU frequency from the period (period is in microseconds)
    uint32_t cpuFrequency = (uint32_t)(1000000.0 / FREQ_PERIODS[freqIndex]);

    // Tick only IO cards that do actual work
    interrupt |= rtcCard.tick(cpuFrequency);
    interrupt |= serialCard.tick(cpuFrequency);
    interrupt |= gpioCard.tick(cpuFrequency);
    interrupt |= soundCard.tick(cpuFrequency);
    interrupt |= videoCard.tick(cpuFrequency);

    if ((interrupt & 0x40) != 0x00) {
      cpu.nmiTrigger();
    }
    if ((interrupt & 0x80) != 0x00) {
      cpu.irqTrigger();
    } else {
      cpu.irqClear();
    }
  }
}

void dump() {
  inputCtx = INPUT_CTX_MEM;

  Serial.println();
  Serial.println("RAM Dump:");
  Serial.println();

  char ascii[16];

  for (size_t i = 0; i < MEM_PER_PAGE; i++) {
    size_t index = i % 16;
    uint8_t value = ram.data[i + (memoryPage * MEM_PER_PAGE)];

    if (index == 0) {
      Serial.print("$");
      Serial.printf("%04X ", (memoryPage * MEM_PER_PAGE) + i);
      Serial.print(": ");
    }

    Serial.printf("%02X ", value);
    ascii[index] = (value >= 0x20 && value <= 0x7E) ? (char)value : '.';

    if (index == 15) {
      Serial.print("| ");
      Serial.print(ascii);
      Serial.println(" |");
    }
  }

  Serial.println();
  Serial.print("Page: ");
  Serial.print(memoryPage);
  Serial.println(" | ([) Prev Page | Next Page (]) |");
  Serial.println();
}

void snapshot() {
  if (!SD.mediaPresent()) { return; }
  if (!SD.exists("Snapshots")) { SD.mkdir("Snapshots"); }

  lastSnapshot = now();
  String path = "Snapshots/";
  String IOpath = "Snapshots/";

  path.append(lastSnapshot);
  path.append(".bin");

  File snapshot = SD.open(path.c_str(), FILE_WRITE);

  if (snapshot) {
    for(uint i = 0; i < (RAM_END - RAM_START); i++) {
      snapshot.write(ram.read(i));
    }
    snapshot.close();
  }
}

void decreaseFrequency() {
  if (isRunning) stopCpuTimer();

  if (freqIndex > 0) {
    freqIndex--;
  } else {
    freqIndex = FREQ_SIZE - 1;
  }

  if (isRunning) startCpuTimer();
}

void increaseFrequency() {
  if (isRunning) stopCpuTimer();

  if (freqIndex < (FREQ_SIZE - 1)) {
    freqIndex++;
  } else {
    freqIndex = 0;
  }

  if (isRunning) startCpuTimer();
}

void toggleRunStop() {
  if (isRunning) {
    stopCpuTimer();
    isRunning = false;
  } else {
    isRunning = true;
    startCpuTimer();
  }
}
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

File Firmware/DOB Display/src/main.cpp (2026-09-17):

#include <Arduino.h>
#include <SPI.h>
#include <ILI9341_t3n.h>
#include <DOBDisplay.h>

void processSerialByte(uint8_t b);
void dispatch(uint8_t type, uint8_t a, uint8_t b);
void render();
void setPixel(uint16_t x, uint16_t y, uint8_t colorIndex);
void renderGraphicsI();
void renderGraphicsII();
void renderText();
void renderMulticolor();
void renderSprites();
void sidISR();
void sidReset();
void sidWrite(uint8_t reg, uint8_t val);
void info();

#define HWSERIAL Serial1

uint8_t  vram[16384];
uint8_t  registers[8];
uint16_t vramAddr = 0;

uint16_t palette[256];
uint8_t  framebuffer[CANVAS_W * CANVAS_H];

uint8_t  serialBuffer[32768];

// AV packet accumulator
uint8_t  pktBuf[4];
uint8_t  pktLen = 0;

time_t   lastRenderTime = 0;
uint8_t  targetFrameTime = 17;  // ~60 FPS

//
// SID AUDIO STATE
//

#define SID_SAMPLE_RATE  44100
#define SID_CLOCK        985248  // PAL 6581

// Attack times in ms, indexed by 4-bit attack nibble
static const uint16_t SID_ATTACK_MS[16]  = {
    2,    8,   16,   24,   38,   56,   68,   80,
  100,  250,  500,  800, 1000, 3000, 5000, 8000
};

// Decay/release times in ms, indexed by 4-bit nibble
static const uint16_t SID_DECAY_MS[16]   = {
    6,   24,   48,   72,  114,  168,  204,  240,
  300,  750, 1500, 2400, 3000, 9000, 15000, 24000
};

struct SIDVoice {
  uint32_t phase;           // 32-bit DDS phase accumulator
  uint32_t phaseInc;        // pre-computed increment per sample
  uint32_t envAccum;        // Q8.24 envelope accumulator (>>24 = level 0-255)
  uint32_t envAttackRate;   // Q8.24 increment per sample during attack
  uint32_t envDecayRate;    // Q8.24 decrement per sample during decay
  uint32_t envReleaseRate;  // Q8.24 decrement per sample during release
  uint8_t  envSustain;      // sustain level 0-255
  uint8_t  envState;        // 0=idle 1=attack 2=decay 3=sustain 4=release
  uint8_t  gatePrev;        // previous gate bit for edge detection
  uint16_t lfsr;            // noise LFSR
  uint8_t  noiseTrigger;    // previous noise clock bit
};

uint8_t     sid[32];
SIDVoice    sidVoice[3];
IntervalTimer sidTimer;

ILI9341_t3n tft = ILI9341_t3n(TFT_CS, TFT_DC, TFT_RESET);

//
// MAIN
//

void setup() {
  pinMode(TFT_BL, OUTPUT);
  pinMode(TFT_RESET, OUTPUT);
  pinMode(SPEAKER, OUTPUT);
  analogWriteResolution(8);  // 8-bit PWM DAC for audio output
  digitalWrite(TFT_BL, HIGH);
  digitalWrite(TFT_RESET, HIGH);

  tft.begin();
  tft.setRotation(3);
  tft.fillScreen(ILI9341_BLACK);

  // Build palette: indices 0-15 from TMS_PALETTE, rest = black
  for (uint16_t i = 0; i < 256; i++) {
    palette[i] = (i < 16) ? TMS_PALETTE[i] : 0x0000;
  }

  Serial.begin(115200);
  HWSERIAL.begin(6000000);
  HWSERIAL.addMemoryForRead(serialBuffer, sizeof(serialBuffer));

  memset(vram, 0, sizeof(vram));
  memset(registers, 0, sizeof(registers));

  sidReset();

  info();
}

void loop() {
  while (HWSERIAL.available()) processSerialByte(HWSERIAL.read());
  while (Serial.available())   processSerialByte(Serial.read());

  if (millis() - lastRenderTime >= targetFrameTime) {
    render();
    lastRenderTime = millis();
  }
}

//
// AV PACKET PROCESSING
//

void processSerialByte(uint8_t b) {
  if (pktLen == 0 && b != AV_SYNC) return;  // re-align
  pktBuf[pktLen++] = b;

  if (pktLen == 4) {
    dispatch(pktBuf[1], pktBuf[2], pktBuf[3]);
    pktLen = 0;
  }
}

void dispatch(uint8_t type, uint8_t a, uint8_t b) {
  switch (type) {
    case AV_TYPE_VIDEO_DATA:
      vram[vramAddr & 0x3FFF] = b;
      vramAddr = (vramAddr + 1) & 0x3FFF;
      break;
    case AV_TYPE_VIDEO_REG:
      registers[a & 0x07] = b;
      break;
    case AV_TYPE_VIDEO_ADDR:
      vramAddr = ((uint16_t)(a & 0x3F) << 8) | b;
      break;
    case AV_TYPE_SOUND:
      sidWrite(a & 0x1F, b);
      break;
    case AV_TYPE_RESET:
      memset(vram, 0, sizeof(vram));
      memset(registers, 0, sizeof(registers));
      vramAddr = 0;
      sidReset();
      break;
  }
}

//
// RENDER
//

void render() {
  uint8_t m1 = (registers[1] >> 4) & 1;
  uint8_t m2 = (registers[1] >> 3) & 1;
  uint8_t m3 = (registers[0] >> 1) & 1;
  uint8_t backdrop = registers[7] & 0x0F;
  uint8_t displayEnabled = (registers[1] >> 6) & 1;

  memset(framebuffer, backdrop, sizeof(framebuffer));

  // R1 bit 6 clear blanks the active area to the backdrop without disturbing
  // VRAM — the usual way to hide a screen while it is being redrawn
  if (displayEnabled) {
    if      (m1 == 0 && m2 == 0 && m3 == 0) { renderGraphicsI();   renderSprites(); }
    else if (m1 == 0 && m2 == 0 && m3 == 1) { renderGraphicsII();  renderSprites(); }
    else if (m1 == 1 && m2 == 0 && m3 == 0) { renderText(); }
    else if (m1 == 0 && m2 == 1 && m3 == 0) { renderMulticolor();  renderSprites(); }
  }

  tft.writeRect8BPP(0, 0, CANVAS_W, CANVAS_H, framebuffer, palette);
}

void setPixel(uint16_t x, uint16_t y, uint8_t colorIndex) {
  if (x >= ACTIVE_W || y >= ACTIVE_H) return;
  if (colorIndex == 0) return;  // transparent - show backdrop
  framebuffer[(y + BORDER_Y) * CANVAS_W + (x + BORDER_X)] = colorIndex;
}

//
// GRAPHICS I MODE - 32x24 tiles, 8x8 each
//

void renderGraphicsI() {
  uint16_t nameTable    = (registers[2] & 0x0F) << 10;
  uint16_t colorTable   = registers[3] << 6;
  uint16_t patternTable = (registers[4] & 0x07) << 11;

  for (uint8_t tileY = 0; tileY < 24; tileY++) {
    for (uint8_t tileX = 0; tileX < 32; tileX++) {
      uint8_t charCode = vram[(nameTable + tileY * 32 + tileX) & 0x3FFF];

      uint8_t colorByte = vram[(colorTable + (charCode >> 3)) & 0x3FFF];
      uint8_t fg = (colorByte >> 4) & 0x0F;
      uint8_t bg = colorByte & 0x0F;

      for (uint8_t row = 0; row < 8; row++) {
        uint8_t patByte = vram[(patternTable + charCode * 8 + row) & 0x3FFF];
        for (uint8_t col = 0; col < 8; col++) {
          uint8_t bit = (patByte >> (7 - col)) & 1;
          setPixel(tileX * 8 + col, tileY * 8 + row, bit ? fg : bg);
        }
      }
    }
  }
}

//
// GRAPHICS II MODE - 32x24 tiles, 3 sections of 256 patterns
//
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

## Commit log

2026-05-03 Cleanup DEV project
    [5-5530843-4.step, 61204021621.step, BAT-HLD-001-THM.step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]
2026-05-04 Finish DEV cleanup
    [Dev Output Board.kicad_pcb, Dev Output Board.step]
2026-05-04 Uppercase DEV
    [Dev Board.kicad_pcb, Dev Board.kicad_sch, Dev Output Board.kicad_pcb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]
2026-05-04 Fix case-sensitive file and folder names (Dev -> DEV)
    [DEV Board.kicad_pcb, DEV Board.kicad_sch, DEV Output Board.kicad_pcb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]
2026-05-16 Add BOMs
    [DEV Board.csv, DEV Board.kicad_sch, DEV Output Board.csv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]
2026-05-19 Finish BOM and add to README
    [DEV Board.csv, DEV Board.kicad_sch, DEV Output Board.csv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]
2026-05-19 Restore exclude from BOM
    [DEV Board.kicad_pcb, DEV Board.kicad_sch]
2026-05-24 Update Dev Output Board silkscreen
    [DEV Output Board.kicad_pcb, DEV Output Board.kicad_sch]
2026-06-15 Change pull up resistor values
    [DEV Board.kicad_pcb, DEV Board.kicad_sch]
2026-06-16 Remove BOM CSV's
    [DEV Board.csv, DEV Output Board.csv]
2026-06-18 Revert pull-up resistor value change
    [DEV Board.csv, DEV Board.kicad_pcb, DEV Board.kicad_sch]
2026-08-04 Name J1 on the Output Board what the schematic names it
    The BOM gave the DEV Output Board's J1 as SPEAKER; the schematic's Value for
    that connector is AUDIO. Every other designator in both boards' BOMs agrees
    with its schematic.
    Source: Hardware/DEV Output Board/Rev 1.0/DEV Output Board.kicad_sch.
    Also adds the documentation backlink and replaces 6502-ASSETS with 6502-DOCS in
    the software table.
2026-08-06 Stop the SID attack envelope wrapping on fast attack rates
    At attack nibble 0 the Q8.24 step is large enough that the accumulator
    sum passes UINT32_MAX and wraps back near zero, so the >= full scale
    test failed and the voice re-attacked every ~2 ms instead of decaying.
    Detect the wrap explicitly and clamp to full scale.
    [main.cpp]
2026-08-06 Fix reset, VDP, ACIA and DOB Display issues from PicoCalc port audit
    - GPIOCard::reset() unregistered every attachment before resetting it,
    so the loop that resets attachments ran zero times; registrations
    now clear in the constructor instead, matching the emulator.
    - Firmware reset only reset three of nine IO devices, leaving stale
    ACIA/VIA/storage/RTC state after a reset; now resets every slot.
    RTCCard::reset() is split into a warm path (was wiping NVRAM) and
    the cold-start path moved into the constructor.
    - VDP frame IRQ was a one-tick pulse the CPU could miss between
    instructions; now held until the status register is read.
    - VDP status read only cleared the frame flag instea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
    [main.cpp]
2026-09-17 Bring the Serial Card's R6551 model in line with the bench
    The status register's DSR (bit 6) and DCD (bit 5) are active low, so a
    permanently connected, permanently ready peer reads 0 in both. This card set
    DSR to mean "ready", with a comment saying as much. Nothing in the BIOS or
    BASIC reads either bit, so nothing changes on screen; the byte is simply now
    the byte a real R6551 returns.
    Four more things came into line with 6502-EMULATOR's ACIA.ts, which was
    corrected against a real R6551 on the bench on 2026-09-17:
    - Clearing DTR (command bit 0) turns the receiver, the transmitter and the
    interrupts off. Every BIOS that has shipped leaves DTR clear only between
    ProbeSerial and InitSC,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
2026-09-18 Say which serial card the DB Emulator models
    The standard Serial Card with CTS EN at ground: CTS, DCD and DSR all tied
    low. That is what the firmware already did, so this is comments and the
    README only. Checked against the bench predicates in 6502-EMULATOR's
    ACIA.ts: with every line at ground the only differences left are the two
    already recorded, TIC 00 and a byte arriving while the receiver is off.
2026-09-21 Cart: index by uint32_t
    A uint16_t index cannot address past 64 KB, so it is the first thing in the
    way of a banked cartridge of 128 KB to 1 MB. The type change alone, with no
    behaviour attached: every call site still passes the same values it did, and
    a 32,768-byte cart still reads exactly as it read before.
2026-09-21 Cart: the banked mapper
    6502-VCS PLAN.md §2: the bank register, the translation, and the rule that
    keeps the reset vectors where the CPU can always reach them — the fixed region
    is the primary chip's last 8 KB whatever the register holds, and `chip` never
    applies to it.
    The design is the two 8 KB windows in internal RAM. A banked cart executes
    from the cart, so every opcode fetch in $C000-$FFFF is a cart read, and on a
    512 KB or 1 MB image those bytes are in PSRAM. Serving fetches from there
    would slow the emulated CPU down across the board and the slowdown would be
    blamed on banking rather than on where the bytes live. So read() is two
    branches and an array index with no PSRAM access at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
2026-09-21 main: pass CPU addresses to the cart and reset the bank register
    read() and write() hand the cart the address off the bus instead of one
    already relative to CART_START. The cart does its own translation, so a flat
    image subtracts CART_START internally and behaves exactly as it did, and a
    banked one runs the address through the mapper without the hot path having to
    know which kind is in the slot.
    reset() calls cart.reset(). The bank register's /MR is on RESB, so a warm
    reset clears it too — a cart that boots the first time and not the second is
    the symptom of leaving that out.
2026-09-21 Status and web API report the cartridge size and bank
    Both status lines and the /api/info payload. Without the bank a banked cart
    is close to undebuggable — whatever is on screen came out of a window that
    nothing else reports — and being able to see it from a browser is most of
    what the web interface is for.
    "unsaved" is beside them because the cartridge writing to itself is the one
    piece of machine state that is lost by pulling the power rather than by a
    reset, and the serial menu and the web interface both grow a way to write it
    out without ejecting.
    Deviation from the plan, which asked for `cart.size` and `cart.bank` on
    `/api/status`: this firmware's endpoint is `/api/info` and ever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
2026-11-02 DEV base plate: a mounting drawing
    Plate Mounting Drawing (SVG and PNG) shows where the DEV Board and the DEV Output Board mount on the base plate, every hole's position, how each hole goes together and the hardware the build needs. I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
2026-11-02 DEV mounting drawing: M2 hardware for the LCD
    The DEV Output Board's LCD mounts on M2 × 10 standoffs with M2 washers.
2026-11-03 Production: stop ignoring production files
    Production/.gitignore was a copy of the Libraries template, whose *.csv rule
    kept each board's bom.csv, designators.csv and positions.csv on one machine
    while its zip and netlist.ipc were committed. The file is gone, as on the
    ACE, which has none. The root .gitignore still covers .DS_Store.
2026-11-03 Production: add the CSV files the DEV Board Rev 1.0 never had
    Their exports were never committed and no longer exist, so these come from
    Fabrication Toolkit's own table generator, run on the PCB without saving it.
    The same run reproduces the KIM Board's, the Clock Card's and the ACE's CSV
    files byte for byte. Every pad in a regenerated netlist.ipc sits at the same
    position as in the committed one, so these describe the board as produced.
2026-11-03 README: the 6502 BUS connector is 732-5401-ND
    The Amazon link listed for it was a plain female header. Digi-Key 732-5401-ND
    is the part this footprint takes.
2026-11-03 DEV mounting drawing: the LCD's screws
    The hardware table listed no screws for the LCD. It now has female-female
    M2 x 10 standoffs and 8 M2 x 6 pan heads, one in each end of each standoff,
    the same fix as the KIM's drawing. That follows the M3 stack; the build's own
    hardware isn't recorded.
2026-11-04 DEV Output Board: Rev 1.0 is what was made, the later silkscreen is Rev 1.1
    JLCPCB's copy of order Y88 is byte-identical to the export in 6502-COB
    ddaceb3, from before this board moved repositories. 3f23ebb later relabelled
    J1 from SPEAKER to AUDIO and added a +, in Rev 1.0's files.
    Rev 1.0 returns to the order: its copper, mask, outline, holes and silk
    regenerate to JLCPCB's files. The later silkscreen becomes Rev 1.1, drawn and
    not ordered. BOM data stays from the later files.
    Both still report 10 net conflicts between the schematic and PCB, as the files
    did before this change. They are not fixed here.
2026-11-04 CAD: top panels and jigs are versioned by board revision
    Tops and jigs move to CAD/<Folder>/<Board>/Rev X/, with a complete folder per
    revision, like Hardware/. Each panel was checked against each revision: all of
    a board's corner mounting holes must land on the panel's holes. Bases hold the
    parts for a whole computer, so they stay where they are.
2026-11-04 PCBs: BOM fields and board-only flags, for clean parity
    The BOM fields and flags on the footprints now match each schematic, and logos and holes with no symbol are marked board-only. Neither can reach a fab layer: the Gerbers and drill files regenerate id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
2026-11-04 REVISIONS.md: what is known about every board revision
    Status, JLCPCB order, the commit each board was made from, Tindie stock, size, mounting holes and what fits it. Made, checked means the order was compared byte for byte with the production zip here. 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
2026-11-04 DEV Board Rev 1.0 back to what JLCPCB made (order Y68)
    The PCB returns to the as-made layout: copper and mask match the order. Later edits
    only changed J6's pad shapes. The production zip is JLCPCB's. Today's schematic and
    BOM are kept, and they match this copper. J6's shield pads are a known symbol and
    footprint difference, not a fault.
2026-11-04 Board images: every revision rendered the same way
    Front and back, at 2400 x 1600, on white and with no background, in the black solder
    mask and white silkscreen the boards are made with. They replace images that came from
    two methods, in nine different sizes.
2026-11-05 BOM: one set of part numbers across AC6502
    Writes the shared parts catalogue into every schematic and PCB. Each part now
    has the same Digikey, Mouser, Jameco, LCSC and Other fields. Junk fields imported
    with library parts are gone, and so is MPN, because the Fabrication Toolkit
    falls back to it and put it in bom.csv's LCSC column.
    bom.csv is now an accurate BOM. Only card edges, solder jumpers and test points
    are excluded. A blank LCSC cell means JLCPCB doesn't place the part.
    Where the silk doesn't print it, Value says what to fit: BAT85, R6551AP, 33pF and
    so on. A do-not-fit resistor says so. Made boards whose silk prints an old value
    keep it, and the known issues in BOM.md will cover th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
2026-11-05 BOM.md: every part, by revision, with known issues and cart files
    BOM.md has a parts list for every revision, with Digi-Key, Mouser and other
    sources, how to tell which revision you have, and the known issues that change
    what to buy or fit. BOM/ holds a Digi-Key and a Mouser file for each revision.
    Revisions with soldered parts also have through-hole files that leave them out.
    The README's old BOM tables disagreed with the schematics, so they now link here.
    Revision histories and build notes stay in the README.
    Where the build notes say to fit something else, the lists now order that: 10k
    pull-ups on ACE Board 1.0, CPU Card 1.0, DEV Board 1.0 and Main Board 1.0 and 1.1,
    and no RESB pull-up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
2026-11-05 DEV Board: no Mouser number for the RJ45
    Mouser's minimum for J1B1211CCD is 120, with none in stock, so a builder can't
    order one there. Digi-Key has discontinued it, and BOM.md says so. Copper, mask,
    paste, silk, outline and drill exports are unchanged.
2026-11-05 Everything derived from the boards, brought up to date
    Board images are re-rendered for every revision whose silk or fitted parts
    changed, so they show SERIAL (DTE) and the rest. The revision histories now say
    what changed on the silk, and wording that pointed at the old BOM tables is gone.
    3D model paths that led nowhere are fixed: old KiCad variables, a folder that no
    longer exists, and models KiCad 10 only ships as STEP. Those boards' STEP files
    and images now include all their parts.
    positions.csv no longer lists parts that aren't fitted. Made and ordered boards'
    fabrication exports are unchanged, and so are DRC and schematic parity.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
2026-11-05 RJ45: Taoglas TMJDD111B083FC2A1D replaces the discontinued J1B1211CCD
    Its datasheet matches J8's pinout, LED polarity and pad positions, so the
    board doesn't change: Gerbers and drill files are identical. Checked on
    paper; not yet fitted to a board.
    Also ignore KiCad's local history folder.
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2026-11-05 Library parts named for what they are, not a part number
    Footprints, symbols and 3D models in "6502 Parts" are named for their
    function and shape (RJ45 Jack LED, CR2032 Holder, 6502 Card Slot, Power
    Switch, SID, ACIA 6551, PIA 6521), so a replacement part with the same
    footprint needs no rename. Every repo carries the same copy of each part,
    re-saved by KiCad 10, and each symbol library holds every symbol its
    schematics use. VCS's 65C02 and 65C22 had wrong pin types; ACE's are now
    in all five. Unused DS01C-254-L-08BE and Mini-Black removed.
    Every revision's Gerbers and drill files export the same before and after.
    DRC is unchanged; ERC loses six missing-symbol warnings. Production files
    for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
2026-11-06 README: shared lines
    A Shared lines section, the same in all five KiCad repos: one 10k pull-up
    on each of RESB, IRQB, NMIB, RDY and BE, on the board with the CPU, and none
    on any other board, so two never sit in parallel. A board's own reset
    circuit pulls RESB low but never carries the pull-up.
2026-11-06 Schematics: bus connectors drawn one way; README: extra pins and HRDB
    Every 6502 bus, cart and card connector on every schematic, made revisions
    included, is drawn one way: a short wire and a global label on each used
    pin, a no-connect flag on each unused one, GND and VCC as global labels,
    and label shapes fixed per signal as the CPU sees it. Bus lines, bus
    entries and local labels for the bus are gone, which clears every "local
    and global labels have same name" ERC warning. Labels match the silk.
    Where bus pins 4 and 6 carry EXP1 and EXP0, or a cartridge grounds them, a
    note on the schematic says what HRDB (High ROM disable bar) does with them.
    The README's new Extra pins section explains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
2026-11-07 Schematics: label shapes follow the signal
    Every global label's shape now shows which way the signal flows at the
    pin it is drawn on: output where it is driven, input where it arrives,
    bidirectional where both, passive for VCC and GND. A bus connector takes
    the board's view: on a board that drives the bus (a CPU board, a
    backplane) the addresses, RWB, SYNC, PHI2 and RESB flow into it and the
    interrupt and control lines come out; on a card a signal flows into the
    edge only if the card drives it (a clock, a reset, an interrupt through
    its diode and jumper) and out of it otherwise.
    The connector redraw had given each label one shape per signal name, so
    address, RWB and PHI2 labels at chip inpu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
2026-11-07 Schematics: drawn as KiCad draws by default
    - Every GND symbol shows its name, 3.81 mm below it, as KiCad places a new
    one: 128 hid it and most sat at 5.08 mm, an older default. Three moved
    aside by hand stay; one on the DEV Board sits left to clear a label.
    - A global label at 270 degrees is right-justified, as KiCad writes it, so
    the cart GND labels no longer lie over their own tie wire (ROM Cart,
    Flash Cart, Keypad Card).
    - CPU Card 1.0, 1.1 and Main Board 1.0: "Jumper ... for original 6502" is
    text on the sheet, spelled right, not a field on the jumper; the field
    is gone from the schematic and the PCB footprint. The schematic-to-PCB
    check is unchanged and every Gerber layer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
2026-11-07 README, BOM, REVISIONS: which revision to make, and the off-board headers
    Every revision now carries one of three labels, with a one-line reason:
    Tested, Proven design (not built at this revision, but its circuit is a
    tested revision's) or Untested. REVISIONS.md shows it in place of the old
    Tested column, BOM.md beside each revision, and a new README section,
    "Which revision to make", gives each board's newest revision and its label.
    All three are generated from one data file, so they can't disagree.
    A new README section, "Off-board headers", says what the small headers such
    as RESET SW, CLOCK ENBL SW, POWER LED and VCC are for: building a board into
    a case, with the case's parts wired to t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
2026-11-07 Tools/cad/: generate a machine's plate, mounting drawing and STL
    make.py writes CAD/Bases/Plate.svg, the mounting drawing and Plate.stl
    from CAD/Assembly.json, and --check, run by derived-check.py, fails when
    any is out of date. setup.sh makes the build123d venv the STL needs. This
    repository has no assembly file yet (CAD.md C7).
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2026-11-08 Tools/cad/: openings for ribbon-cable box headers; no loose acrylic
    Every box header for a ribbon cable (bus or GPIO) gets a 1.5 mm opening, as
    its plug comes up through the top (owner). A piece of a top that would hold
    no mounting hole is dropped into the opening round it, with a note.
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2026-11-09 Tools/cardedge/: cart holes at 5.0 and 13.0 mm; refilled pours are Proven
    The owner's ruling (KICAD.md K28): a cart's M3 holes go 5.0 mm from the top
    edge and the sides, its M2 holes 13.0 mm from the sides, each pair centred.
    They were 4.849 and 4.95 mm from the sides, a slip in Fusion 360. Proven
    design now covers pours refilled with DRC and the netlist check passing, as
    moving a card's outline refills its pours.
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2026-11-09 Board images: bare FR4 in its own colour, so a card's bare tab shows
    render.py drew the core with no colour, so KiCad showed bare board almost
    as dark as the black mask, and the cards' new mask-free tabs couldn't be
    seen. The core is now FR4 natural, which shows wherever there's no mask: a
    card's tab, and the thin ring where the mask stops short of a pad. Every
    image is rendered again; the masked areas are unchanged.
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2026-11-09 flow.py: a jumper to a rail sets a level; it drives nothing
    The card-edge PHI2 label on the Video Card pointed the wrong way, and
    derived-check passed it. flow.py took any jumper to VCC or GND for a
    source: JP2, which can tie U4's enable to VCC, sits behind JP1 on the
    PHI2 net, so the card seemed to drive PHI2 out to the bus. A jumper to a
    rail is now a pull-up or -down, as a resistor is, whether it ships open or
    bridged; a switch to a rail (a reset button) still drives. The rule in
    KICAD.md K25 is unchanged.
    That flipped both PHI2 labels on every card with a PHI2-enable jumper
    pair, made revisions included: COB RTC Card, VERA Helper and VGA Card
    1.0 and 1.1, VGA Card Pro 1.0, Video Card 1.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
2026-11-13 Silkscreen: no JLCPCB order-number marker on the boards not yet made
    JLCPCB stopped printing order numbers in May 2026, and its help page now asks
    for no JLCJLCJLCJLC text on the silkscreen. The text is removed from every
    revision not yet made; Gerbers prove only F_Silkscreen changed. Made revisions
    keep theirs, which JLCPCB ignores.
    Tools: audit.py fails on the marker on a revision not made or ordered,
    table.py shows it in CONSISTENCY.md's Names on silk, and newrev.py drops it
    when it copies a made revision. Synced from 6502-COB.
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2026-11-13 Tools/README: how to script a board with pcbnew without crashing it
    KiCad 10.0.3's pcbnew segfaults when a script reads objects after a
    board.Remove(), often at Python's shutdown, and macOS shows a crash window
    (2026-11-13, during the ROM Cart 1.1 work; the same on 2026-11-02 and
    2026-11-06). The rules: read first and remove last, end with os._exit(0)
    after saving, hold the board, and never call WriteDRCReport.
2026-11-13 DEV Board: no Rev 1.1; RESB stays driven by the Teensy
    The DEV Board stands in for a Main Board and owns reset, so RESB stays
    driven out through U3 with no pull-up, and a DEV goes only on a passive
    backplane, never the COB Backplane Pro (owner, 2026-11-13). R1-R4 have
    read 10k in Rev 1.0 since 2026-11-04, so no revision is needed.
    - BOM.md build notes: the stale "1k in the files" reworded; RESB is now
    a connection rule, not a limit waiting on a new revision
    - README Shared lines: the DEV Board is the exception on RESB
    - table.py accepts the missing RESB pull-up by name (Pull-ups column)
    - offboard.json: the J3 reason no longer names a Rev 1.1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
2026-11-13 Production files: one set of settings, one plugin, and a check
    The headless runner behind regen.py hard-coded the Fabrication Toolkit's
    AUTO TRANSLATE off, while every board's options file, which the plugin's
    window reads, has it on. AUTO TRANSLATE applies JLCPCB's rotation fixes for
    SOIC, SOT-23, TSSOP and similar packages, so the placement files of 21
    revisions not yet made (and the RAM Card 1.1, regenerated after its routing)
    gave surface-mount chips rotated 90 to 180 degrees from what JLCPCB's
    assembly needs. Nothing made or ordered came from them.
    - Tools/production/ replaces Tools/bom/toolkit.py: options.json is the one
    set of settings, written byte for byte into every revision's fo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
2026-11-14 DEV Board 1.1: Rev 1.0's circuit, its IC designators at the chips' ends
    On every revision not yet made, an IC's designator and value sit centred at
    the short ends of its footprint (aligned to an end's edge where the centre is
    taken). A through-hole IC shows its value; a surface-mount IC hides it, as the
    owner ruled from the renders: they don't fit. A ZIF socket is measured from its
    silk outline. audit.py checks the values (KICAD.md K36). Every board proved
    silk only with gproof.py.
    The owner keeps a DEV Board 1.1 so the family is one set of Rev 1.1s (K39):
    U3's and U6's designators move; the values stay hidden (all surface mount);
    the logo takes K40's place. Building a Rev 1.0: nothing to d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
2026-11-14 Board logos generated from Bebas Neue (K32)
    Tools/logos/generate.py draws a board logo from the font's own outlines:
    "6502" at the logo's height H (the digits' 720 font units, overshoots
    included), the board's name in capitals at half that scale, centred on
    the digits, 0.16 H after the 2, with the font's spacing and kerning. The
    design was measured from the 50 traced footprints (design.json); 44
    matched it to within 0.004 H. The font is the copy the DOCS and the
    KIMulator ship, with its licence (OFL.txt).
    Every footprint in the 6502 Logos libraries is now drawn by it, named
    "6502 <Board> Logo <H>mm", its origin at the centre of the printed
    shapes, its picture in CAD/Logos/<Board>/6502 <Boar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
2026-11-14 CAD/Logos: remove the Affinity Designer logo file
    Tools/logos/generate.py draws every board logo and its PNG from Bebas
    Neue since K32, so the Affinity file is no longer the source, and it no
    longer matches the six logos the owner ruled onto the design.
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2026-11-14 Tools: a made revision can be replaced by a newer design (K39)
    orders.json gains "replaced"; register.py names the made boards and
    their Tindie stock on the drawn revision that took their number, in
    place of a hard-coded Backplane Pro 1.1. apply.py drops the old
    Backplane Pro 1.1 R5 entry, a part the new 1.1 doesn't have. Synced to
    all five.

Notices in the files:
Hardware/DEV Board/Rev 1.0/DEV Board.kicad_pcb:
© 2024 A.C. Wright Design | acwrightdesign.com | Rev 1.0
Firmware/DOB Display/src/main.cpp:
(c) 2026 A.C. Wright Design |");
